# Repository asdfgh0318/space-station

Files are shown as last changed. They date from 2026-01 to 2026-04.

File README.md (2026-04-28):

<p align="center">
  space-station banner
</p>

# space-station

Multi-band radio telescope and antenna tracker — Raspberry Pi 4B + Waveshare Stepper Motor HAT (B) + 2× NEMA 17 + RTL-SDR. Fully 3D-printed alt-az mount, FastAPI dashboard, swappable RF feeds.

## Documentation

- **[`tech_stack.md`](tech_stack.md)** — north star: hardware stack and credentials
- **[`plan_2.md`](plan_2.md)** — active rebuild plan (current)
- **[`docs/archive/plan_1.md`](docs/archive/plan_1.md)** — historical Phase 1 plan
- **[`docs/archive/merge_plan.html`](docs/archive/merge_plan.html)** — upcoming `inmarsat-sniffer` integration plan

## Quick start

```bash
# On the Raspberry Pi (Debian Trixie)
bash scripts/bootstrap_rpi.sh
source ~/.bashrc
ss-test           # smoke-test motors (dry-run)
ss-start          # FastAPI dashboard on :8080
```

## Layout

```
tracker/      motor controller, geostationary look-angle math, sniffer stub
web/          FastAPI dashboard with Tracker + Inmarsat tabs
scripts/      bootstrap + bench test CLI
vendor/       reserved for inmarsat-sniffer submodule (not yet vendored)
docs/archive/ historical plans and integration design
```

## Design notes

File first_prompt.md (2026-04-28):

hi claude lets start building the radiotelescope i prepared a techstack.md file wich is our north star and wil be updated now lets tackle the first point of the file i want to connect on my bench the motors to the rpi hat and rpi i have an sdcard inserted lets setup github repo wich is ppublic and lets work this way you generate the plan of a stem and when im happy with your steps i accept it and then you make github isues out of all tasks and then execute them using a worktree of faster subagents after the plan is executed ill test the features and only then we commit

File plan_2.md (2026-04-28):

# plan_2 — Rebuild from scratch with inmarsat seams

## Context

The user is re-running the workflow from `first_prompt.md`: generate a plan → user
approves → GitHub issues → subagents in worktrees → user tests → commit. The previous
plan (`plan_1.md`) was executed at commit `bd0c259` and produced the current
`tracker/` + `web/` + `scripts/` + `requirements.txt`.

The user now wants a clean rebuild that bakes in **architectural seams for the
upcoming `inmarsat-sniffer` integration** (analyzed in `merge_plan.html`), without
actually pulling in the GPL-3.0 C binary yet. After this rebuild lands, the inmarsat
merge becomes a small, additive PR rather than a refactor.

Canonical sources of truth:
- `tech_stack.md` — Waveshare Stepper Motor HAT (B), NEMA 17, RTL-SDR, GUI control
- `tracker/config.yaml` (current) — 1:1 GT2 belt, 32× microstepping, Warsaw site
- `merge_plan.html` — target architecture for inmarsat sidecar

(Project memory is stale on the drive choice — it still says TMC2209 + 5:1. Will
update memory after the rebuild lands.)

---

## Scope

**Wipe:**
- `tracker/` (controller.py, config.yaml, __init__.py)
- `web/` (app.py, __init__.py)
- `scripts/` (bootstrap_rpi.sh, motor_test.py, spin_test.py)
- `requirements.txt`

**Move to `docs/archive/`:**
- `plan_1.md`
- `merge_plan.html`

**Keep untouched:**
- All `.stl`, `.STEP`, `.gcode`, `.pb`, `.pdf`, `.svg`, `.exe`
- `tech_stack.md`, `first_prompt.md`, `aplikacja_wok_rezydencja.md`, `README.md`
- `radio-telescope-plan.html`, `radio-telescope-plan.pdf`, `radio-telescope-plan-images/`
- `banner.svg`, `.gitignore`, `.git/`

**No code from `alphafox02/inmarsat-sniffer` enters this repo in this plan.**

---

## Target tree after rebuild

```
space-station/
├── tracker/
│   ├── __init__.py
│   ├── config.yaml          # HAT + bands + targets + sniffer seams
│   ├── controller.py        # lgpio motor control, ~300 LOC
│   ├── targets.py           # geostationary AZ/EL math, presets — STUB
│   └── sniffer.py           # subprocess supervisor placeholder — STUB
├── web/
│   ├── __init__.py
│   └── app.py               # FastAPI, jog UI, scaffolded "Inmarsat" tab — placeholder
├── scripts/
│   ├── bootstrap_rpi.sh     # OS bring-up + inmarsat build deps (no clone yet)
│   └── motor_test.py        # CLI bench tester
├── vendor/
│   └── .gitkeep             # reserved slot for inmarsat-sniffer submodule (later)
├── docs/
│   └── archive/
│       ├── plan_1.md
│       └── merge_plan.html
├── plan_2.md                # copy of this plan, committed at root
├── requirements.txt
├── tech_stack.md            (kept)
├── first_prompt.md          (kept)
├── README.md                (kept)
└── [all hardware assets kept]
```

---

## Tasks (one GitHub issue per task)

### Task 0 — Clean repo, archive old plans
- `git rm -r tracker/ web/ scripts/ requirements.txt`
- `mkdir -p docs/archive vendor`
- `git mv plan_1.md docs/archive/plan_1.md`
- `git mv merge_plan.html docs/archive/merge_plan.html`
- `touch vendor/.gitkeep`
- Verify with `git status` that only the targeted files moved/deleted
- **No commit yet** — gate on user testing per `first_prompt.md`

### Task 1 — `tracker/config.yaml` (with inmarsat seams)
Layout based on the current config but reorganized so future band/target/sniffer
config lives in well-named blocks instead of dormant `lnb:` and `sdr:` stubs:

```yaml
site:        # Warsaw 52.2297, 21.0122, 100m elevation
tracker:     # alt-az, driver: waveshare_hat_b, az/el axes (HAT pins, 1:1 belt, 32× µstep)
bands:                          # NEW — band profiles
  l_band:                       # 1525–1559 MHz Inmarsat
    enabled: false
    sample_rate: 2400000
    gain: 40.0
    notes: "Direct RTL-SDR, no LO/LNB"
  ku_band:                      # 10–12 GHz dish + LNB (future)
    enabled: false
    lnb:
      model: "Inverto IDLB-SINL40"
      lo_low: 9750000000
      lo_high: 10600000000
      switch_freq: 11700000000
      gpio:
        power_pin: 23
        voltage_select_pin: 25
        tone_pin: 26
targets:                        # NEW — geostationary presets, computed AZ/EL
  alphasat_25e:
    name: "Inmarsat 4F2 / Alphasat (25°E)"
    sat_longitude: 25.0
    band: "l_band"
  inmarsat_4f3_98w:
    name: "Inmarsat 4F3 (98°W)"
    sat_longitude: -98.0
    band: "l_band"
sniffer:                        # NEW — sidecar config, dormant until merge
  enabled: false
  binary_path: "vendor/inmarsat-sniffer/build/inmarsat-sniffer"
  feed_udp_port: 5000
  skip_c_channel: true          # Pi 4 default per upstream README
  web_port: 8888                # sniffer's own UI (iframed in our dashboard)
```

### Task 2 — `tracker/controller.py`
Same shape and quality as the current implementation (lgpio backend, trapezoidal
accel, click CLI, sim mode), built fresh:
- `StepperAxis` — step/dir/enable via lgpio
- `AntennaTracker` — two-axis orchestration, position state, jog/goto/home/park
- CLI: `status`, `goto az el`, `home`, `park`, `step --motor az/el --count N --dir cw/ccw`
- Sim fallback when lgpio unavailable
- ~300–400 LOC

### Task 3 — `tracker/targets.py` (STUB module)
Pure math, no I/O, no SDR, no submodule yet:
- `geostationary_azel(site_lat, site_lon, sat_lon) -> (az_deg, el_deg)`
  Standard formula: spherical geometry from observer to GEO arc.
- `load_targets(config) -> dict[name, Target]`
- `Target.dataclass(name, sat_longitude, band, az, el)`
- CLI smoke test: `python -m tracker.targets list` prints AZ/EL for each preset
  from current site coords (Warsaw → Alphasat ≈ 165°/27°).
- ~80 LOC. No subprocess, no SDR.

### Task 4 — `tracker/sniffer.py` (STUB module)
Placeholder for the future subprocess supervisor:
- `class SnifferSidecar` with `start()`, `stop()`, `status()`, `is_running()`
  All methods raise `NotImplementedError("inmarsat-sniffer not vendored yet — see docs/archive/merge_plan.html")` for now,
  so any caller sees a clear error.
- `SnifferStatus` dataclass (`pid`, `running`, `last_decode_at`, `decode_count`)
  defined now so the API is stable.
- ~40 LOC. Importable, doesn't crash, doesn't pretend to work.

### Task 5 — `scripts/motor_test.py`
Same scope as current implementation:
- `spin --motor 1/2 --steps N --speed S --dir cw/ccw`
- `sweep --motor N` — speed ramp
- `test-all` — both motors smoke test
- `interactive` — terminal arrow keys
- `--dry-run` flag, click + rich, reads `tracker/config.yaml`

### Task 6 — `scripts/bootstrap_rpi.sh`
Same structure as current Trixie bootstrap, plus inmarsat build deps preinstalled
so the future merge is a one-command `cmake && make`:

```bash
# Existing (motor + Python venv)
sudo apt install -y python3-lgpio python3-pip python3-venv pigpio-tools \
                    librtlsdr-dev rtl-sdr i2c-tools
# NEW — for future inmarsat-sniffer build
sudo apt install -y cmake build-essential pkg-config \
                    libacars2-dev libzmq3-dev libmosquitto-dev
```
- RTL-SDR udev rules + DVB blacklist (kept)
- I2C / USB-boot enablement (kept)
- Aliases: `ss-update`, `ss-start`, `ss-test`, `ss-debug` (kept)
- Smoke tests: lgpio connect, Python deps import, RTL-SDR detection
- Adds a TODO comment near the inmarsat deps pointing at `merge_plan.html`

### Task 7 — `web/app.py`
Same dashboard scope as today, plus a scaffolded "Inmarsat" tab:
- All current motor-control endpoints (`/api/jog`, `/api/goto`, `/api/home`,
  `/api/park`, `/api/motors/{enable,disable}`, `/api/stop`, `/api/set-limit`)
- `/ws` live position WebSocket
- Retro-terminal styling
- **NEW**: tab switcher in UI between "Tracker" (current) and "Inmarsat"
- **NEW**: `/api/sniffer/status` returns `{enabled: false, reason: "stub — see merge_plan"}`
- **NEW**: Inmarsat tab shows a "not configured yet — pending hardware/integration"
  placeholder card linking to `docs/archive/merge_plan.html`
- ~500–600 LOC

### Task 8 — `requirements.txt`
Same minimal set as today — no new deps for the sniffer stubs:
```
lgpio
fastapi
uvicorn[standard]
websockets
pyyaml
click
rich
numpy
```

### Task 9 — Save plan + write README hook
- Copy this plan file to repo root as `plan_2.md`
- Add a one-line section in `README.md` linking to `plan_2.md` and the
  archived `merge_plan.html` (README is currently essentially empty)

---

## Execution method (per `first_prompt.md`)

1. ☐ User approves this plan (via `ExitPlanMode`)
2. ☐ Create one GitHub issue per task (Task 0–9) with `gh issue create`
3. ☐ Spawn parallel subagents in **isolated git worktrees** — Tasks 1–8 are
   independent enough for parallel execution; Task 0 must run first; Task 9 last
4. ☐ User runs verification on RPi + bench
5. ☐ Only after user confirms tests pass, merge worktrees and commit

**Do not commit anything until the user has tested on hardware.**

---

## Verification

Run on the dev machine first:
- `python -c "from tracker.controller import AntennaTracker; AntennaTracker.from_config('tracker/config.yaml')"` — imports clean in sim mode
- `python -m tracker.targets list` — prints AZ/EL for Alphasat 25°E from Warsaw
  (expected: AZ ≈ 165°, EL ≈ 27°). Acts as numerical regression on the math.
- `python -c "from tracker.sniffer import SnifferSidecar; SnifferSidecar().status()"` — raises `NotImplementedError` cleanly
- `python scripts/motor_test.py test-all --dry-run` — no errors, both motors enumerated
- `uvicorn web.app:app --port 8080` → open browser → "Tracker" and "Inmarsat" tabs
  both render; Inmarsat tab shows the placeholder card
- `bash -n scripts/bootstrap_rpi.sh` — script parses, no syntax errors

Run on RPi (user does this on the bench):
- `bash scripts/bootstrap_rpi.sh` — completes without errors, all deps installed
- `python scripts/motor_test.py test-all` — both motors spin
- `python -m web.app --port 8080` → browser → arrow keys move motors
- Endpoint wizard saves limits to `config.yaml`

After the user signs off:
- Commit Task 0–9 as a single atomic rebuild commit (or one commit per task —
  user's call at commit time)
- Update memory: drive choice is HAT + 1:1, not TMC2209 + 5:1
- Push to `origin/main`

---

## What this plan does NOT do (deferred)

These are explicitly out-of-scope for this rebuild and belong to the inmarsat merge PR:
- Cloning `alphafox02/inmarsat-sniffer` as a submodule
- Building the C binary
- Writing the actual subprocess supervision logic
- UDP/MQTT decode listener
- Live decode WebSocket channel
- Iframe of the sniffer's :8888 UI
- L-band feed hardware acquisition decision
- Project root LICENSE selection (still no LICENSE file — to be settled before
  pulling in GPL-3.0 code, **before** the merge PR, not in this rebuild)

The seams in this plan make those changes additive, not invasive.

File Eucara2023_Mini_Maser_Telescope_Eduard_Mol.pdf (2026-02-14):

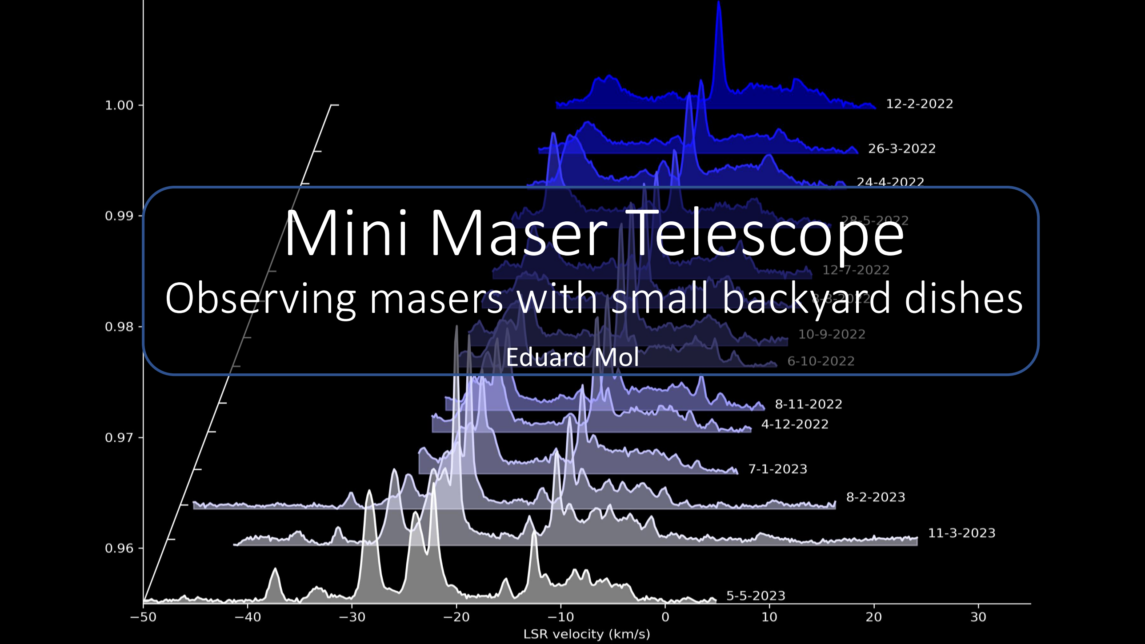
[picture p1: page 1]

# Mini Maser Telescope

## Observing masers with small backyard dishes

Eduard Mol

## What are masers? (and why are they interesting?)

- Essentially the microwave equivalent of LASERs
- Stimulated emission
- Specific molecules:
- OH (1612- 1720 MHz),
- methanol (6.668 and 12.2 GHz)
- water (22.2 GHz)
- Star formation and red giant stars
- Variable

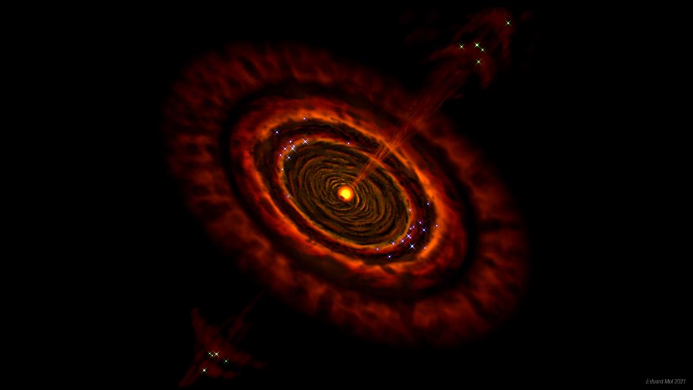
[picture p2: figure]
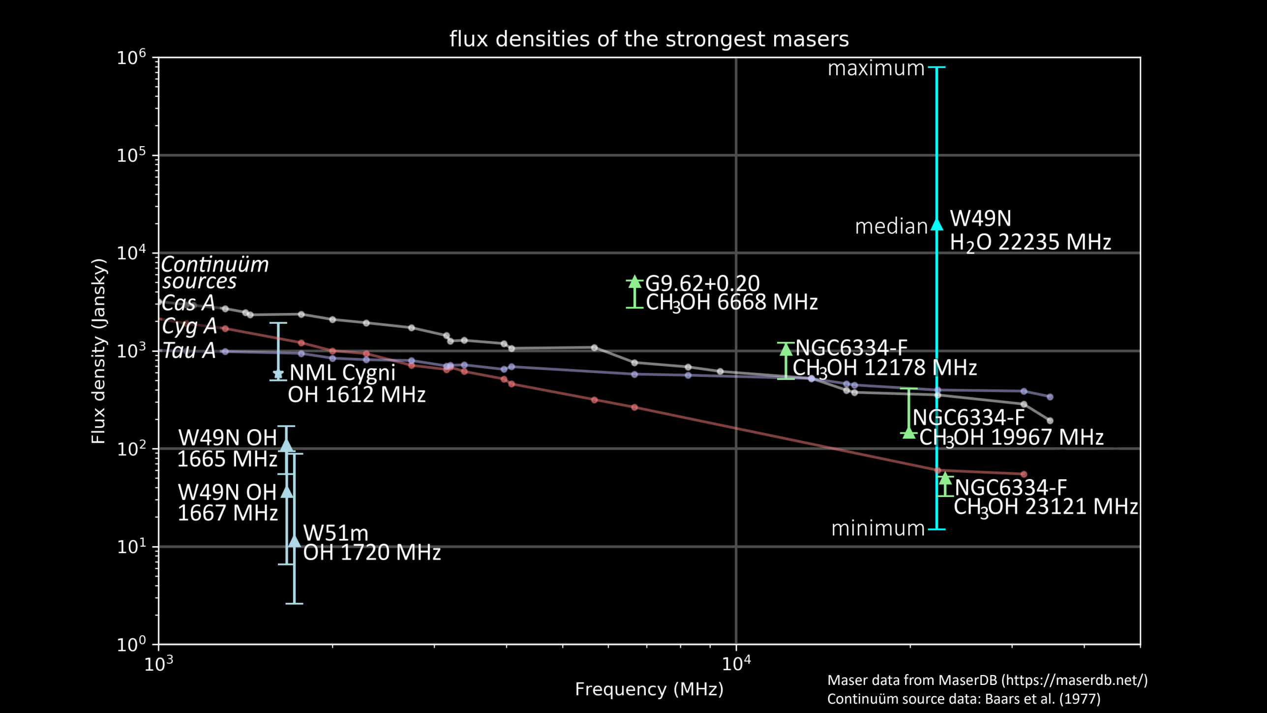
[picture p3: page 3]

Maser data from MaserDB (https://maserdb.net/) Continuüm source data: Baars et al. (1977)

## 12.2 GHz methanol masershardware and observation methods

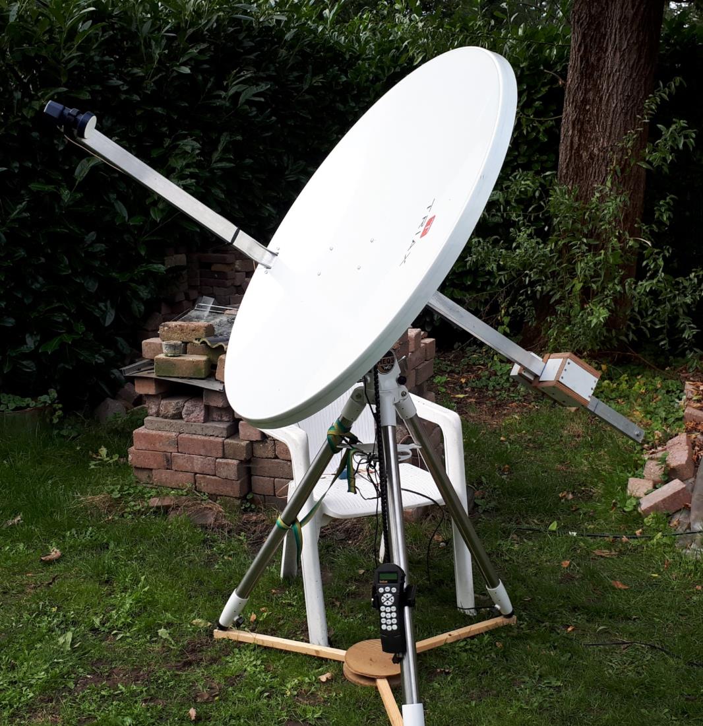
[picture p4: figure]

- 1 metre dish on HEQ5 mount
- Inverto Ku band PLL LNB
- 22KHz tone for band switching
- Software: SDR#/ IF average
- Post-processing in python/ excel
- Frequency to LSR velocity

## 12.2 GHz methanol masers: results

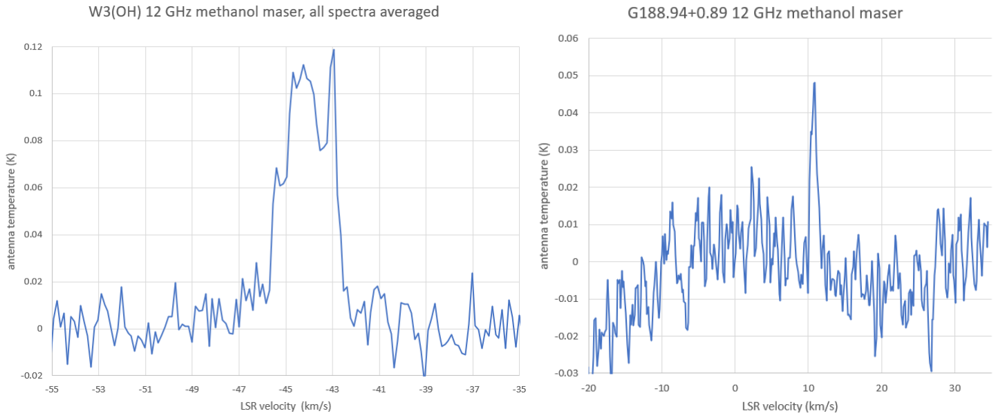
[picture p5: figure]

- W3(OH)
- G188.94+0.89

## Water masers at 22.2 GHz

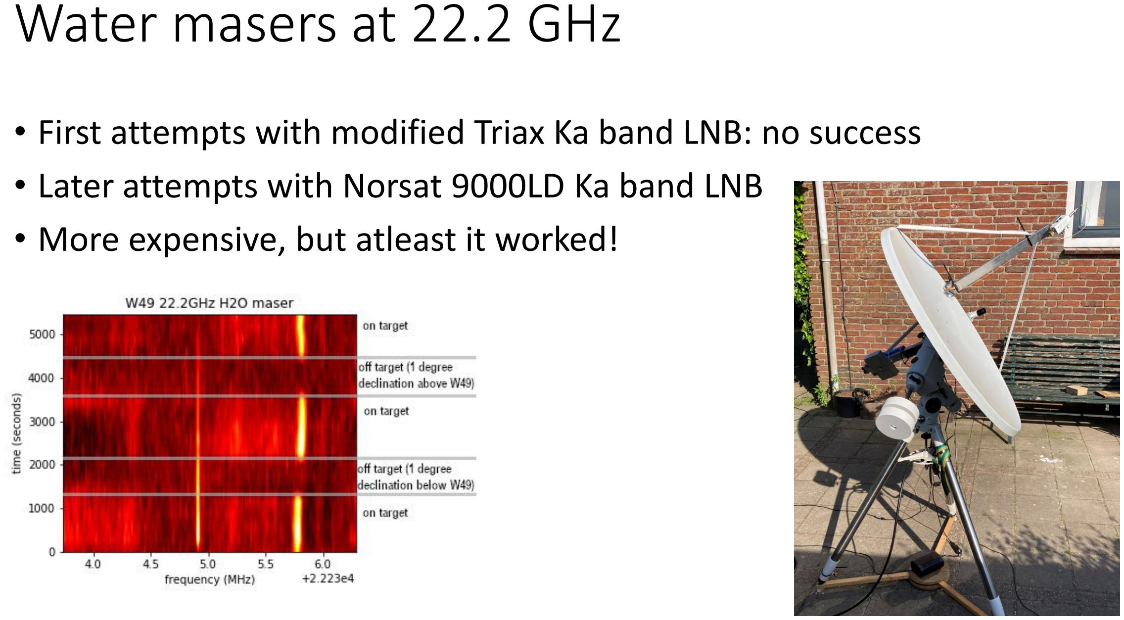
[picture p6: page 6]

- First attempts with modified Triax Ka band LNB: no success
- Later attempts with Norsat 9000LD Ka band LNB
- More expensive, but atleast it worked!

## 22.2 GHz setup technical info

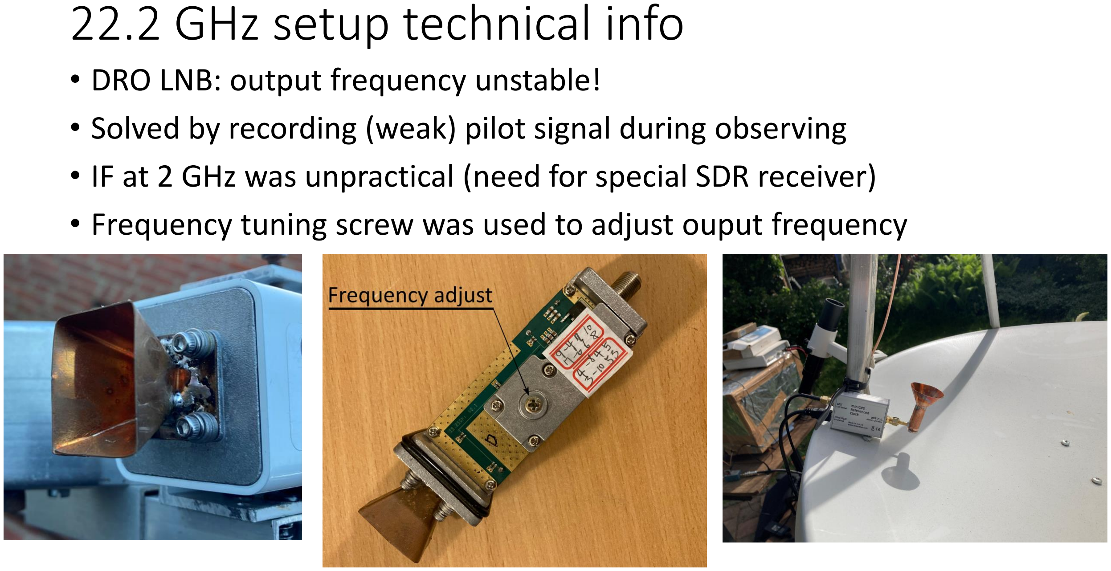
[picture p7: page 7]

- DRO LNB: output frequency unstable!
- Solved by recording (weak) pilot signal during observing
- IF at 2 GHz was unpractical (need for special SDR receiver)
- Frequency tuning screw was used to adjust ouput frequency

## Water masers: The results so far

- Several sources were detected:
1. W49
2. W51
3. W3(OH)/ W3(2)
4. Orion KL
5. W75
6. G34.403+0.232
7. Cepheus A
8. NML Cygni
9. G25.624+1.050

W49

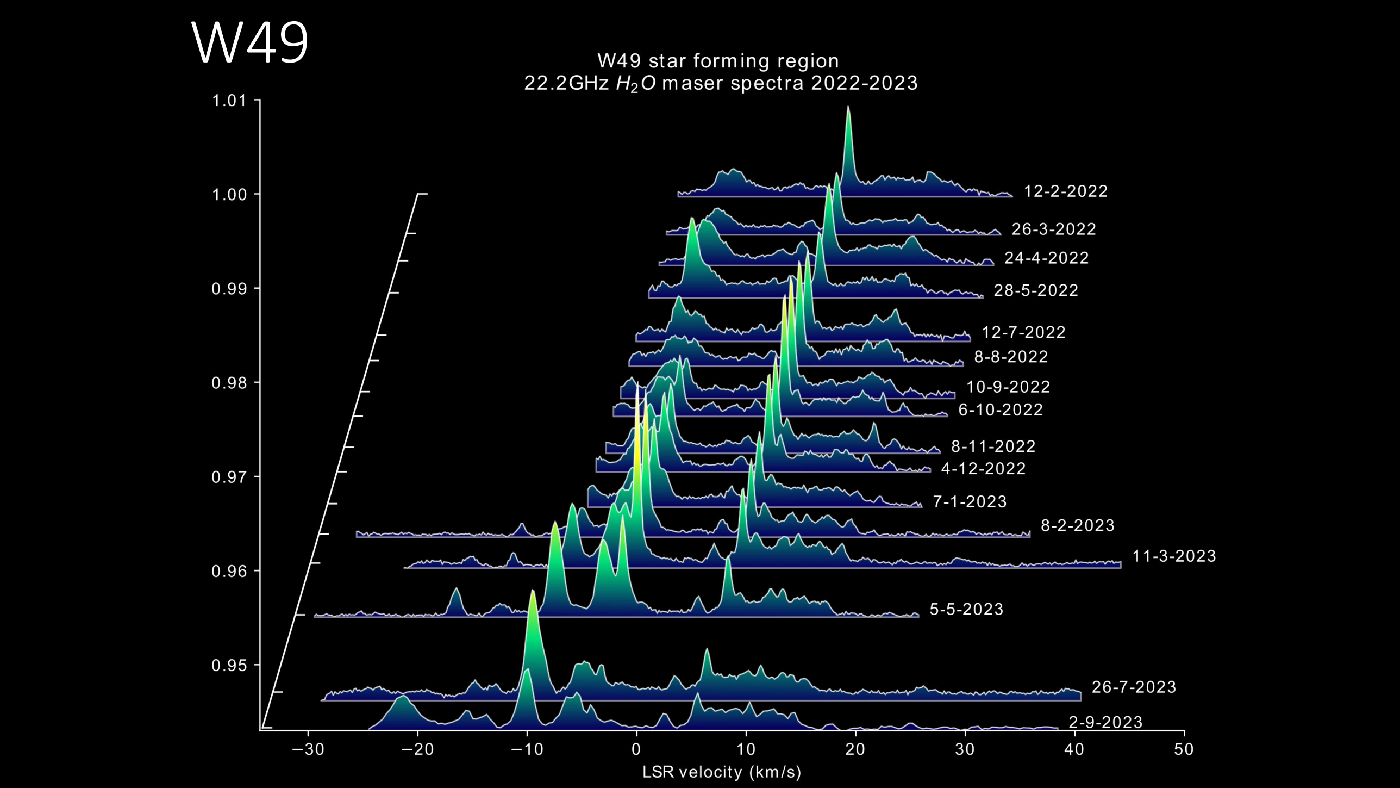
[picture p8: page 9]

## Conclusion and outlook

- 12.2 GHz Methanol masers:
+ Relatively easy and cheap to set up
- 12.2 GHz masers are challenging to detect
- 22.2 GHz Water masers
+ several sources can be detected
+ Tracking variability is possible
- equipment is more expensive/ more difficult to obtain

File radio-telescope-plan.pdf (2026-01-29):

Prepared January 2026 | For review and consultation

# Radio Telescope & Antenna Tracker Project

## Project Vision

Incremental build of an antenna-tracked radio telescope system, starting with automated weather satellite reception and a weather prediction AI for Warsaw, then expanding into radio astronomy and citizen science contributions.

## PHASE 1: Automated Weather Satellite Station +

## Weather AI

### 1A: Meteor-M LRPT Reception (No Tracker Needed) — ~$60-100

The easiest and fastest entry point. Meteor-M N2-3/N2-4 are Russian polar-orbiting weather satellites transmitting at 137 MHz. Multiple passes over Warsaw daily. No tracking needed (omnidirectional antenna). Will be available into the 2040s.

Important context: All NOAA POES satellites (15, 18, 19) were decommissioned in mid-2025. Meteor-M is now the primary 137 MHz weather satellite. From Warsaw, GOES satellites are NOT visible (geostationary over Americas).

Hardware

Item | Cost | Notes
RTL-SDR Blog V4 | ~$35 | Main receiver
QFH antenna (DIY) | ~$10-15 | Copper pipe + PVC, circularly polarized
SAW filter + LNA (137 MHz) | ~$15-25 | Optional but recommended for Warsaw RFI
Raspberry Pi 4/5 | ~$50-80 | Or use existing PC
SMA cables, adapters | ~$10

Software Stack

SatDump (satdump.org) — all-in-one: satellite tracking, SDR control, decoding, image generation. Has built-in automation (auto-track, auto-record, auto-decode). Replaces the old chain of 6+ programs

Runs on Raspberry Pi 5 or any Linux box

Outputs: visible light images, infrared images, false-color composites, map overlays

What you get

1 km/px resolution images of Europe (JPEG compressed but good)

3 spectral channels (visible, near-IR, thermal IR)

Multiple passes/day, automated capture 24/7

Cloud patterns, storm systems, snow cover over Warsaw region

### 1B: HRPT Reception with Antenna Tracker — ~$300-500 additional

The big upgrade: high-resolution, uncompressed multi-channel imagery. This requires building the antenna tracker (your main engineering project).

•

•

•

•

•

•

•

Receivable satellites from Warsaw with HRPT (1.7 GHz, L-band)

Satellite | Operator | Status | Data
Meteor-M N2-3 | Roscosmos | Active | 6 channels, 1 km, uncompressed
Meteor-M N2-4 | Roscosmos | Active | 6 channels, 1 km, uncompressed
Metop-B | EUMETSAT | Until ~2027 | 6 channels AVHRR, 1 km
Metop-C | EUMETSAT | Until ~2030 | 6 channels AVHRR, 1 km
AWS (Arctic Weather Sat) | ESA | Active | Microwave radiometer

Hardware — Antenna Tracker (custom build)

Item | Cost | Notes
2x NEMA23 stepper motors | $30-60 | Torque for dish + wind
2x TMC2209 stepper drivers | $10-20 | Silent, reliable
ESP32 dev board | $8-12 | Rotator controller
GT2 timing belt + pulleys (80T+20T) | $15-20 | 4:1 first stage reduction
Worm gear set (or 3D printed) | $15-30 | Second stage, 10:1-15:1
6200/6201 bearings (4-6x) | $10-20 | AZ and EL axes
2040 aluminum extrusion | $20-40 | Frame structure
3D printed parts (PETG) | $20-25 | Gear housings, mounts, adapters
Slip ring (12-wire) | $10-15 | Cable management through AZ axis
Steel plate/tube (base) | workshop | Welded base for rooftop mount
Weatherproof enclosure | $15-25 | For electronics
AS5600 magnetic encoders (2x) | $5-10 | Position feedback

Hardware — RF Chain

Item | Cost | Notes
80-100cm offset satellite dish | $0-50 | Used, from classifieds (OLX.pl)
L-band helicone feed (3D printed) | $5-10 | Popular open-source design
Nooelec SAWbird+ GOES LNA | ~$35 | 0.5 dB NF, filtered for 1.7 GHz
Airspy Mini (upgrade from RTL-SDR) | ~$100 | 12-bit, 6 MHz BW, much better for HRPT

Tracker Software (your code)

Rotator Controller (ESP32, C/C++):
├── Stepper motor control (AccelStepper library) ├── AS5600 encoder feedback (I2C)
├── EasyComm2 protocol over serial/WiFi
├── Web interface for manual control
├── Homing routine (limit switches or encoder) └── Wind stow mode (auto-park in high wind)

Host Software (Python, Raspberry Pi):
├── SatDump integration (autotrack + decode)
├── Satellite pass prediction (pyorbital/skyfield) ├── Rotator command interface (rotctld/Hamlib) ├── Image post-processing pipeline
├── Database for captured images + metadata
└── API for weather AI module

What you get

1 km/px UNCOMPRESSED images, 6 spectral channels

Thermal IR for cloud-top temperatures

Near-IR for vegetation, water vapor

Multiple satellites per day = more frequent coverage of Warsaw

Raw data for serious weather analysis

### 1C: Geostationary Satellite Reception (Fixed Dish) — ~$50-150

### additional

Add continuous weather monitoring from Elektro-L (Russian geostationary satellite being repositioned to cover Europe in late 2025/2026).

•

•

•

•

•

Setup

Small fixed dish (60-80cm) pointed at Elektro-L N°3 (14.5°W from Warsaw = ~30° elevation, ~245° azimuth)

Same L-band LNA + SDR as HRPT setup (can share or add second RTL-SDR)

SatDump decodes LRIT/HRIT

Full-disk images every 30 minutes, continuously

Alternative: EUMETCast via DVB-S2 — standard satellite TV setup pointed at Hotbird 13°E, provides Meteosat data. Requires EUMETSAT registration (free for non-commercial/educational use).

### 1D: Weather Prediction AI — Software Project

This is the software centerpiece: an AI system that learns weather patterns from your satellite imagery and predicts weather for Warsaw.

•

•

•

•

Architecture

┌─────────────────────────────────────────────────────────┐
│ | Weather AI System | │
├─────────────────────────────────────────────────────────┤
│ | | │
│ DATA COLLECTION | │
│ ├── Satellite images (your captures) | │
│ │ | ├── Meteor-M LRPT (137 MHz, automated) | │
│ │ | ├── Meteor-M/Metop HRPT (1.7 GHz, tracked) | │
│ │ | └── Elektro-L HRIT (geostationary, continuous) | │
│ ├── Ground truth weather data | │
│ │ | ├── IMGW API (Polish Met Institute) | │
│ │ | ├── OpenWeatherMap API (current + historical) | │
│ │ | └── Your own weather station (optional, future) | │
│ └── Timestamp + geolocation metadata | │
│ | | │
│ DATA PIPELINE | │
│ ├── Image preprocessing | │
│ │ | ├── Georeferencing (map projection) | │
│ │ | ├── Crop to Warsaw region (~200km radius) | │
│ │ | ├── Normalize channels | │
│ │ | ├── Cloud classification (IR thresholding) | │
│ │ | └── RFI artifact removal | │
│ ├── Feature extraction | │
│ │ | ├── Cloud coverage % | │
│ │ | ├── Cloud motion vectors (consecutive images) | │
│ │ | ├── Cloud-top temperature distribution | │
│ │ | ├── Visible albedo patterns | │
│ │ | └── Temporal sequences (last N images) | │
│ └── Storage (PostgreSQL + image files) | │
│ | | │
│ AI MODELS | │
│ ├── Nowcasting (0-6 hours) | │
│ │ | ├── ConvLSTM / U-Net for cloud motion prediction | │
│ │ | ├── Input: sequence of satellite images | │
│ │ | └── Output: predicted cloud/rain patterns | │
│ ├── Short-term forecast (6-24 hours) | │
│ │ | ├── Transformer-based sequence model | │
│ │ | ├── Input: satellite images + weather features | │
│ │ | └── Output: temperature, precipitation, cloud cover │
│ └── Evaluation | │
│ | ├── Compare vs actual weather (IMGW data) | │
│ | ├── Compare vs official forecast (IMGW/ECMWF) | │
│ | ├── Track accuracy metrics over time | │
│ | └── Skill score relative to persistence forecast | │
│ | | │
│ DASHBOARD (Web) | │
│ ├── Live satellite image viewer | │
│ ├── AI prediction display with confidence | │
│ ├── Comparison: AI vs actual vs official forecast | │
│ ├── Historical accuracy charts | │
│ └── Alerts for severe weather detection | │
│ | | │
└─────────────────────────────────────────────────────────┘

Tech Stack

Python — main language (PyTorch/TensorFlow, SatDump integration, data pipeline)

PostgreSQL + TimescaleDB — time-series weather data + image metadata

FastAPI — backend API

React or Svelte — dashboard frontend

PyTorch — model training (ConvLSTM, U-Net, or transformer)

Docker — containerized deployment on Raspberry Pi 5 or mini PC

Open-Source Models to Build On

NPM (github.com/seominseok0429/Data-driven-Precipitation-Nowcasting-Using-Satellite-Imagery) — directly uses satellite imagery, 2 km resolution

OpenClimatefix skillful_nowcasting — DeepMind DGMR reimplementation

ConvLSTM implementations for sequence prediction

Awesome-LWMs (github.com/jaychempan/Awesome-LWMs) — curated list of weather AI models

Training Data Strategy

Bootstrap: Start collecting satellite images + corresponding IMGW weather data from day 1

Pre-train: Use publicly available satellite datasets (SEVIR, EarthNet2021) for initial model training

Fine-tune: Once you have weeks/months of Warsaw-specific data, fine-tune on your own captures

Iterate: Continuously retrain as more data accumulates

Warsaw-Specific Weather Data Sources

IMGW (Instytut Meteorologii i Gospodarki Wodnej) — Polish meteorological data API

OpenWeatherMap — free tier: current weather, 5-day forecast, historical data

Open-Meteo — free, open-source weather API, historical + forecast data

ECMWF — European Centre for Medium-Range Weather Forecasts (open data)

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
## PHASE 2: Radio Astronomy (Future, ~$100-300

## additional)

After the weather station is operational, add radio astronomy capability to the same tracked dish:

Swap/add a 1420 MHz feed horn + SAWbird+ H1 LNA

Hydrogen line detection and Milky Way mapping

Join SARA, contribute data

Same tracker, same SDR infrastructure

PHASE 3: Large Dish + Advanced Targets (Future, ~$500-1500)

Upgrade to 2-3m dish (used TVRO)

Upgrade SDR to SDRplay RSPdx (14-bit)

Pulsar detection attempts

Join SatNOGS network, Wow@Home

Multi-band capability

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
## Project Repository Structure

space-station/
├── firmware/ | # ESP32 rotator controller
│ | ├── src/
│ | │ | ├── main.cpp
│ | │ | ├── stepper_control.cpp
│ | │ | ├── easycomm.cpp | # EasyComm2 protocol
│ | │ | ├── encoder.cpp | # AS5600 position feedback
│ | │ | └── web_server.cpp | # Status + manual control
│ | └── platformio.ini
├── tracker/ | # Host-side tracking software
│ | ├── scheduler.py | # Satellite pass scheduler
│ | ├── rotator.py | # Rotator communication
│ | ├── satdump_integration.py # SatDump automation hooks
│ | └── config.yaml
├── weather-ai/ | # Weather prediction AI
│ | ├── data/
│ | │ | ├── collectors/ | # IMGW, OpenWeatherMap scrapers
│ | │ | ├── pipeline.py | # Image preprocessing
│ | │ | └── dataset.py | # PyTorch dataset class
│ | ├── models/
│ | │ | ├── nowcast.py | # ConvLSTM nowcasting model
│ | │ | ├── forecast.py | # Transformer forecast model
│ | │ | └── evaluate.py | # Accuracy metrics
│ | ├── api/
│ | │ | └── main.py | # FastAPI backend
│ | └── train.py
├── dashboard/ | # Web frontend
│ | ├── src/
│ | └── package.json
├── hardware/ | # CAD files, wiring diagrams
│ | ├── rotator/ | # 3D print STL files
│ | ├── antenna/ | # QFH, feed horn designs
│ | └── enclosure/
├── docs/
│ | ├── build-guide.md
│ | └── calibration.md
├── docker-compose.yml
└── README.md

## Implementation Order

### Sprint 1: Get Images Flowing

Order RTL-SDR V4, build QFH antenna

Install SatDump on Raspberry Pi / PC

Receive first Meteor-M LRPT image

Set up automated capture (SatDump autotrack)

Build image storage database

Start collecting IMGW/Open-Meteo weather data for Warsaw

### Sprint 2: Build the Tracker

Design rotator in CAD (Fusion 360 / FreeCAD)

3D print gear housings and structural parts

Weld steel base frame

Assemble mechanical system

Write ESP32 firmware (stepper control + EasyComm2)

Integrate with SatDump for automated HRPT tracking

### Sprint 3: HRPT Reception

Acquire/build dish (80-100cm) + L-band feed

Install LNA + cabling

First tracked HRPT capture

Set up multi-satellite automated schedule

### Sprint 4: Weather AI v1

Build data pipeline (satellite images → preprocessed dataset)

Implement baseline model (ConvLSTM for cloud motion)

Train on accumulated data + public datasets

Build dashboard with live images + predictions

Start tracking prediction accuracy vs actual weather

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
### Sprint 5: Iterate & Expand

Improve AI model based on accuracy data

Add Elektro-L geostationary reception

Add radio astronomy capability (1420 MHz feed)

Join SARA / SatNOGS communities

## Verification

### Phase 1A (LRPT)

First Meteor-M image captured within first evening

SatDump autotrack captures 4+ passes per day unattended

Images show recognizable cloud patterns over Europe

### Phase 1B (HRPT + Tracker)

Rotator responds correctly to EasyComm2 commands

Gpredict satellite tracking test: rotator follows predicted pass

HRPT image quality visibly superior to LRPT (sharper, more channels)

Tracker survives wind test (weights attached to simulate dish wind load)

### Phase 1D (Weather AI)

Dashboard shows latest satellite images + weather data

Nowcast model produces cloud predictions for next 1-3 hours

Track "skill score" vs persistence baseline (just predicting "same as now")

After 1+ month of data: compare AI accuracy vs IMGW official forecast

## Sources

SatDump (https://www.satdump.org/) — all-in-one satellite decoding software

Beyond POES: Amateur Satellite Reception (https://www.satdump.org/posts/beyond-poes-amateur-satellite-reception/) — post-NOAA landscape

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
Meteor-M Reception Guide (https://www.a-centauri.com/articoli/meteor-satellite-reception) — Jacopo's comprehensive guide

HRPT Beginners Guide (https://www.rtl-sdr.com/a-comprehensive-beginners-guide-to-hrpt-weather-satellite-reception/)

SatDump Automation (https://www.rtl-sdr.com/automating-noaa-apt-and-meteor-m2-lrpt-reception-with-satdump-1-1-2/)

Tysonpower DIY Rotator (https://www.rtl-sdr.com/building-a-diy-azel-antenna-rotator-for-satellite-tracking/)

SatNOGS Rotator v3 (https://wiki.satnogs.org/SatNOGS_Rotator_v3)

NPM Precipitation Nowcasting (https://github.com/seominseok0429/Data-driven-Precipitation-Nowcasting-Using-Satellite-Imagery)

DGMR Reimplementation (https://github.com/openclimatefix/skillful_nowcasting)

Awesome Large Weather Models (https://github.com/jaychempan/Awesome-LWMs)

SARA (https://radio-astronomy.org/) — Society of Amateur Radio Astronomers

SatNOGS (https://satnogs.org/) — satellite ground station network

Radio JOVE (https://science.nasa.gov/citizen-science/radio-jove/)

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
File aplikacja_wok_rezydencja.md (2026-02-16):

# Aplikacja na rezydencję WOK Warszawa 2026
## Temat przewodni: EKSPERYMENT

**Zespół:** Adam, Stas, Maksym (@dontriskit)
**Projekt:** Radioteleskop DIY + system neonów reaktywnych na dane SDR

---

## Tekst kuratorski (kontekst)

> Tegorocznym hasłem przewodnim jest eksperyment. To właśnie przestrzeń spokojnej pracy, nieśpiesznej eksploracji własnych pomysłów, taka, która sprzyja podążaniu za ciekawością, wydaje nam się dziś szczególnym luksusem. Eksperymentowanie wymaga namysłu, w niektórych wypadkach implikuje doświadczenia zmysłowe, w innych – ich brak. W każdym wypadku z eksperymentem wiąże się ryzyko nierozpoznania, bycia niezrozumianym, zdezinterpretowaną. Podczas eksperymentowania w WOK osoby twórcze będą mogły w możliwie bezpiecznej przestrzeni prototypować, testować pomysły i rozwiązania oraz swobodnie podążać za własnym procesem. To, co zostaje po eksperymentowaniu z eksperymentem, nie jest produktem, nie podlega logice utowarowienia, lecz pozostaje świadectwem trajektorii…

---

## 1. Jak rozumiecie temat tegorocznej edycji rezydencji?
*(maksymalnie 1800 znaków ze spacjami)*

Eksperyment to słowo, które jednakowo silnie rezonuje w laboratorium i w pracowni. W nauce to kontrolowana procedura – hipoteza, pomiar, weryfikacja. W sztuce to gest otwarcia na niewiadome. Nasz projekt lokuje się dokładnie na tym przecięciu i czerpie z obu tradycji, nie przynależąc w pełni do żadnej.

Budujemy radioteleskop – urządzenie do odbioru fal elektromagnetycznych z kosmosu. To dosłowny eksperyment: nie wiemy, co usłyszymy. Fale radiowe są niewidoczne, niesłyszalne, niewyczuwalne bez pośrednictwa technologii. Eksperymentujemy więc z samym aktem percepcji – rozszerzamy ludzkie zmysły za pomocą anteny, odbiornika SDR i kodu, próbując uchwycić to, co jest obecne wokół nas, ale niedostępne. Tekst kuratorski mówi o doświadczeniach zmysłowych i ich braku – nasz projekt żyje właśnie w tej szczelinie: czynimy słyszalnym to, co z natury jest nieme.

Eksperymentujemy też z materialnością i ekonomią narzędzi. Teleskop jest drukowany 3D z recyklingowanych części, za budżet poniżej 200 euro. Testujemy, czy narzędzia obserwacji kosmosu mogą istnieć poza instytucjami dysponującymi dużymi środkami – demokratyzacja nasłuchu jako praktyka twórcza. Pracujemy w trójkę, łącząc programowanie, elektronikę i rzeźbę świetlną – sam ten układ jest eksperymentem w kolaboracji.

System neonów, przekształcający dane radiowe w pulsacje światła, jest eksperymentem translacji – próbą nadania widzialnej, cielesnej formy temu, co niezmysłowe. Ryzykujemy niezrozumienie: czy to nauka? Czy sztuka? Ale właśnie ta nieokreśloność, ta przestrzeń między dyscyplinami, jest naszym miejscem pracy. Eksperyment rozumiemy jako prawo do procesu bez gwarancji produktu – do podążania za sygnałem, dosłownie i metaforycznie, bez pewności, dokąd nas zaprowadzi.

---

## 2. Koncepcja na proces rezydencyjny
*(maksymalnie 1800 znaków ze spacjami)*

Nasz proces rezydencyjny składa się z trzech splecionych ścieżek, które zbiegają się w instalację – otwartą stację nasłuchową. Pracujemy jako trio – każdy wnosi odmienną wrażliwość i kompetencję, a proces wzajemnego uczenia się jest częścią eksperymentu.

Pierwsza ścieżka: budowa. Drukujemy 3D elementy mechaniczne trackera antenowego, montujemy obrotowe mocowanie na osi azymutu i elewacji, kalibrujemy system automatycznego śledzenia obiektów na niebie. Pracujemy z otwartym kodem, drukarką Ender 3 i odbiornikiem RTL-SDR podłączonym do Raspberry Pi. To proces z natury powolny – każdy wydruk trwa godziny, kalibracja wymaga powtarzalnych, cierpliwych prób. Czas druku staje się czasem namysłu i rozmowy.

Druga ścieżka: translacja. Stas buduje system neonowych lamp reagujących na strumień danych z odbiornika SDR w czasie rzeczywistym. Sygnały satelitów meteorologicznych, emisja wodoru na częstotliwości 1420 MHz, kosmiczny szum tła – zostają przełożone na pulsacje, rytmy i natężenie światła. Nie w logice precyzyjnej wizualizacji danych, lecz bliżej synestezji – neon jako zmysł, którego nam brakuje, organ percepcji radiowej.

Trzecia ścieżka: nasłuch. Regularne sesje obserwacyjne, podczas których kierujemy antenę w różne obszary nieba i słuchamy. Sesje są otwarte – zapraszamy współrezydentów i odwiedzających. Nie obiecujemy odkrycia. Obiecujemy uważność wobec sygnałów, które docierają do nas nieustannie, niezależnie od tego, czy ktokolwiek ich słucha.

Po rezydencji pozostanie działająca stacja, archiwum sesji i otwarty kod – zapis trajektorii eksperymentu. Wszystko publikujemy open source, zapraszając innych do kontynuacji i modyfikacji. Eksperyment nie kończy się z rezydencją – rozgałęzia się, staje się wspólny, wymyka się autorom.

---

## Notatki robocze

### Kluczowe motywy do podkreślenia:
- **Nieśpieszność** – druk 3D = godziny czekania, kalibracja = powtarzalność, nasłuch = cierpliwość
- **Ryzyko niezrozumienia** – projekt na granicy sztuki i nauki, żadna strona nie "uznaje" w pełni
- **Nie-produkt** – stacja nasłuchowa to proces, nie obiekt; dane płyną, neony pulsują, nic nie jest "skończone"
- **Demokratyzacja** – <200 EUR, open source, drukarka za 800 zł
- **Zmysłowość / jej brak** – fale radiowe → neon = czynienie niewidzialnego widzialnym
- **Trajektoria** – archiwum sesji jako zapis drogi, nie celu

### Elementy techniczne projektu:
- Radioteleskop: RPi 4 + RTL-SDR, PETG 3D print, belt-driven alt-az mount
- Pasma: VHF (137 MHz weather sats), L-band (1420 MHz hydrogen), Ku-band (12.2 GHz masers)
- System neonów: dane SDR → przetwarzanie → sterowanie jasnością/pulsacją neonów
- Całość open source na GitHub

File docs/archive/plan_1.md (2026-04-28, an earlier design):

# Step 1: Bench Motor Control via Waveshare Stepper Motor HAT (B)

## Context

Starting fresh. The user has a Raspberry Pi 4B with a Waveshare Stepper Motor HAT (B) and 2x NEMA 17 steppers on the bench. Old Phase 0 code (written for TMC2209 standalone drivers) is being deleted — we start over with the Waveshare HAT approach.

- `tech_stack.md` is the north star
- Belt drive: 1:1, 20T GT2 pulleys on both ends
- Microstepping: DIP switches only (no software control)
- Resolution at 1/16: 200 × 16 × 1 = 3200 microsteps/rev → 0.1125°/step
- Credentials in `tech_stack.md` — leave as-is

---

## Tasks

### 0. Clean repo — delete old code & docs
**Delete these directories entirely:**
- `tracker/` — old TMC2209 controller code
- `sdr/` — SDR capture/processing
- `web/` — old FastAPI dashboard
- `weather/` — empty collectors
- `targets/` — maser catalog (will recreate if needed)
- `scripts/` — old install script
- `hardware/` — outdated CAD (worm gear), specs, wiring
- `docs/` — old project plan & research
- `data/` — empty data dirs

**Delete these files:**
- `requirements.txt` — will recreate for new stack

**Keep:**
- All `.stl`, `.gcode`, `.STEP` files
- `.pb` files (raw data)
- `tech_stack.md`, `first_prompt.md`
- `README.md`, `banner.svg`, `.gitignore`
- `aplikacja_wok_rezydencja.md`
- PDFs (`Eucara2023...`, `radio-telescope-plan.pdf`)
- `radio-telescope-plan-images/`
- `Windows11InstallationAssistant.exe`

### 1. Create `tracker/config.yaml` — HAT pin mapping + belt drive
- Waveshare HAT (B) GPIO pins (STEP/DIR/ENABLE only, no mode pins):
  - Motor 1 (AZ): STEP=19, DIR=13, ENABLE=12
  - Motor 2 (EL): STEP=18, DIR=24, ENABLE=4
- Belt drive 1:1, 20T GT2 pulleys, 200 steps/rev, 1/16 microstepping
- `home_switch_enabled: false` for bench mode
- Site: Warsaw coordinates
- Pin mapping to be verified against Waveshare wiki during implementation

### 2. Create `tracker/controller.py` — motor controller for Waveshare HAT (B)
Fresh, lean motor controller (~300 LOC) built for the HAT:
- `StepperAxis` class: step/dir/enable GPIO control via pigpio (RPi.GPIO fallback)
- `AntennaTracker` class: two-axis control, position tracking
- Trapezoidal acceleration profiles
- Bench mode: skip homing when no limit switches
- CLI: `--status`, `--goto az el`, `--home`, `--park`, `--steps motor count`

### 3. Create `scripts/motor_test.py` — bench test CLI
Standalone test tool (~200 LOC) using `click` + `rich`:
- `spin --motor 1 --steps 200 --speed 100 --dir cw`
- `sweep --motor 1` — speed ramp test
- `test-all` — smoke test both motors
- `interactive` — arrow keys control in terminal
- `--dry-run` for testing without GPIO
- Loads pins from `tracker/config.yaml`

### 4. Create `web/app.py` — GUI control panel
Fresh web dashboard (~400 LOC) with FastAPI:
- **Position display**: current az/el in degrees + step count
- **Keyboard control**: Arrow keys = jog, Shift+Arrow = fast jog, Space = stop
- **Jog pad**: visual arrow buttons + step size selector (0.01°–45°)
- **Motor enable/disable** toggle
- **Endpoint wizard**: capture current position as axis limit, save to config
- **Bench mode indicator**: shows when homing switches are disconnected
- WebSocket live position updates

### 5. Create `scripts/bootstrap_rpi.sh` — RPi setup script
Bootstrap script (~100 LOC) for fresh RPi OS:
- Install system packages (pigpio, i2c-tools, rtl-sdr, etc.)
- Enable I2C, start pigpiod
- Clone repo / git pull
- Python venv + requirements
- Convenience aliases: `ss-update`, `ss-start`, `ss-test`
- Smoke test (pigpio connection)

### 6. Create `requirements.txt` — fresh dependencies
Only what's needed for the HAT motor control + web UI:
- pigpio, RPi.GPIO (motor control)
- fastapi, uvicorn, websockets (web UI)
- pyyaml (config)
- click, rich (CLI tools)
- numpy (if needed for calculations)

---

## Files Summary

| File | Action | Scope |
|---|---|---|
| `tracker/`, `sdr/`, `web/`, etc. | Delete | Clean old code |
| `tracker/config.yaml` | New | HAT config |
| `tracker/controller.py` | New | ~300 LOC |
| `scripts/motor_test.py` | New | ~200 LOC |
| `web/app.py` | New | ~400 LOC |
| `scripts/bootstrap_rpi.sh` | New | ~100 LOC |
| `requirements.txt` | New | Fresh deps |

---

## Execution Method (from first_prompt.md)

1. **This plan** → user approves
2. **Create GitHub issues** — one per task (0–6)
3. **Execute in worktree** — launch subagents in isolated worktrees to implement each task
4. **User tests** on the bench (RPi + HAT + motors)
5. **Commit only after testing passes**

---

## Verification

1. **On dev machine**: `python scripts/motor_test.py test-all --dry-run` — no errors
2. **On RPi**: `bash scripts/bootstrap_rpi.sh` — all deps installed
3. **On RPi**: `python scripts/motor_test.py test-all` — both motors spin
4. **On RPi**: `python -m web.app --port 8080` → open browser → arrow keys move motors
5. **On RPi**: endpoint wizard saves limits to config.yaml

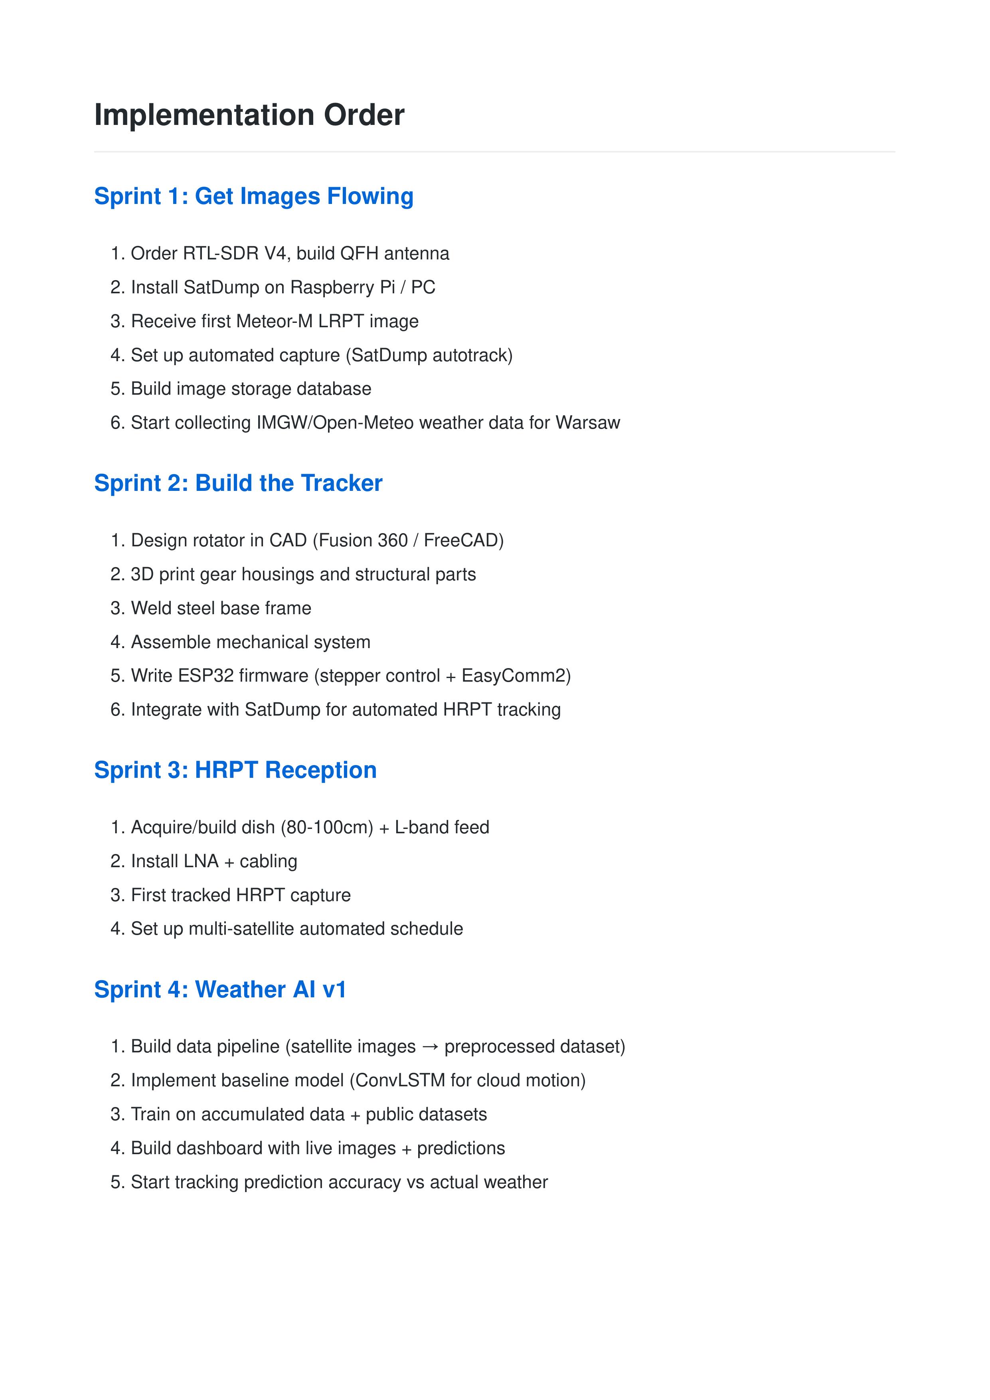
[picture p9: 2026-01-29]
radio-telescope-plan-images/page-11.jpg

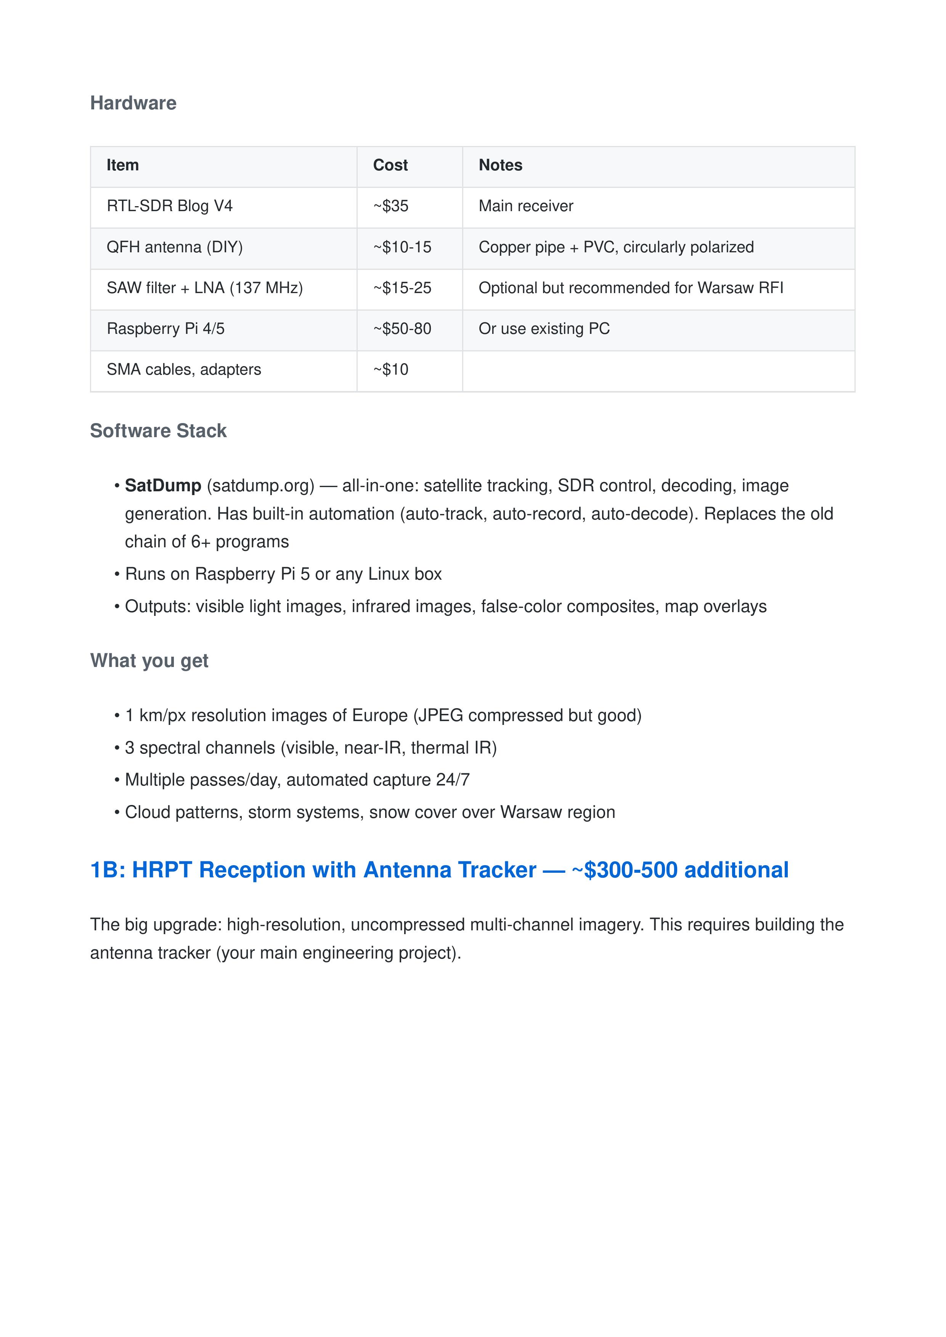
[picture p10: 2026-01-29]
radio-telescope-plan-images/page-02.jpg

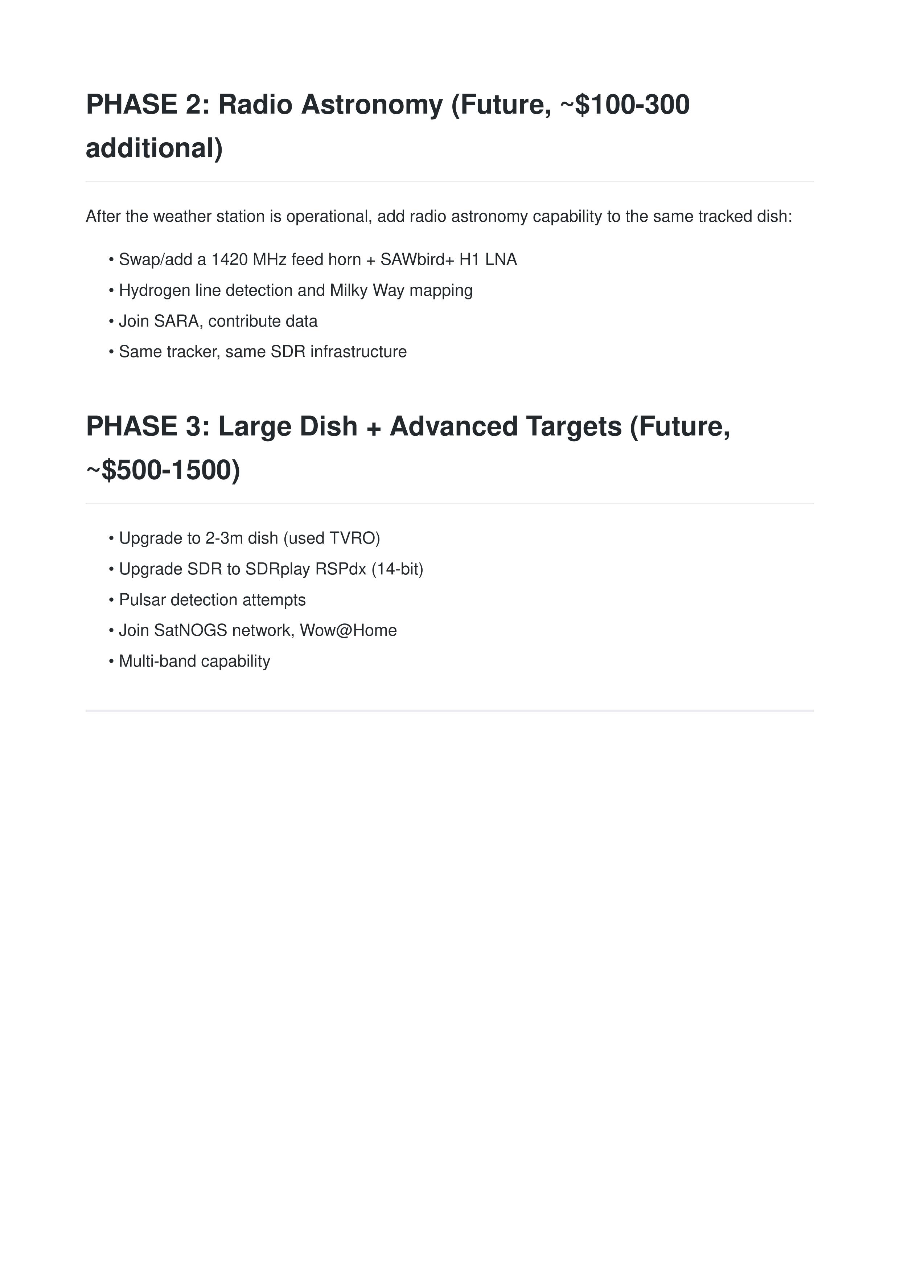
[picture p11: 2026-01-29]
radio-telescope-plan-images/page-09.jpg

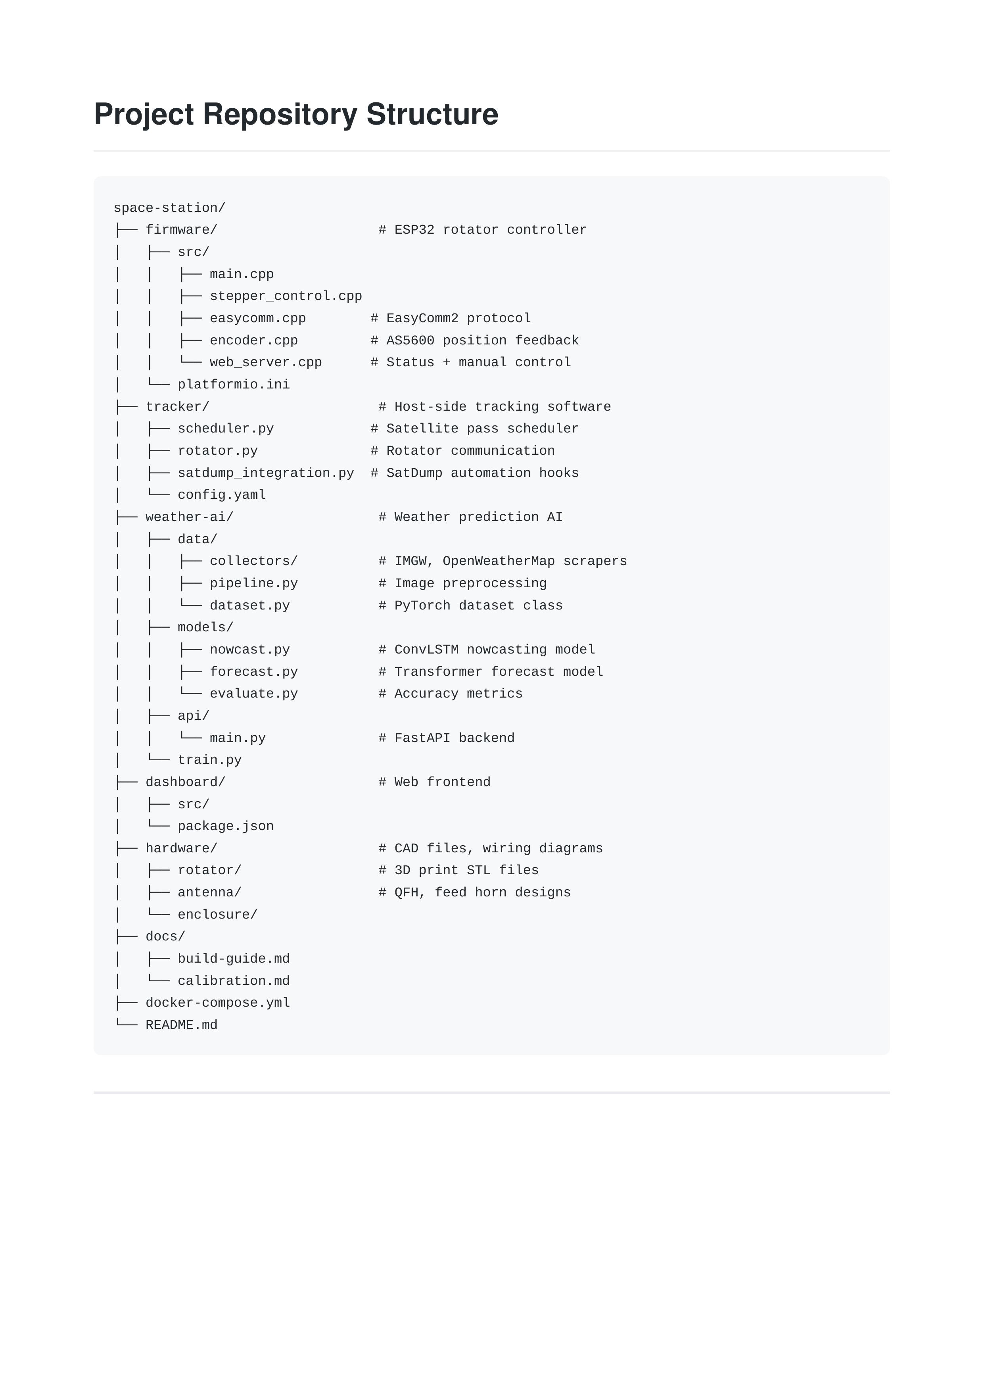
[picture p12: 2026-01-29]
radio-telescope-plan-images/page-10.jpg

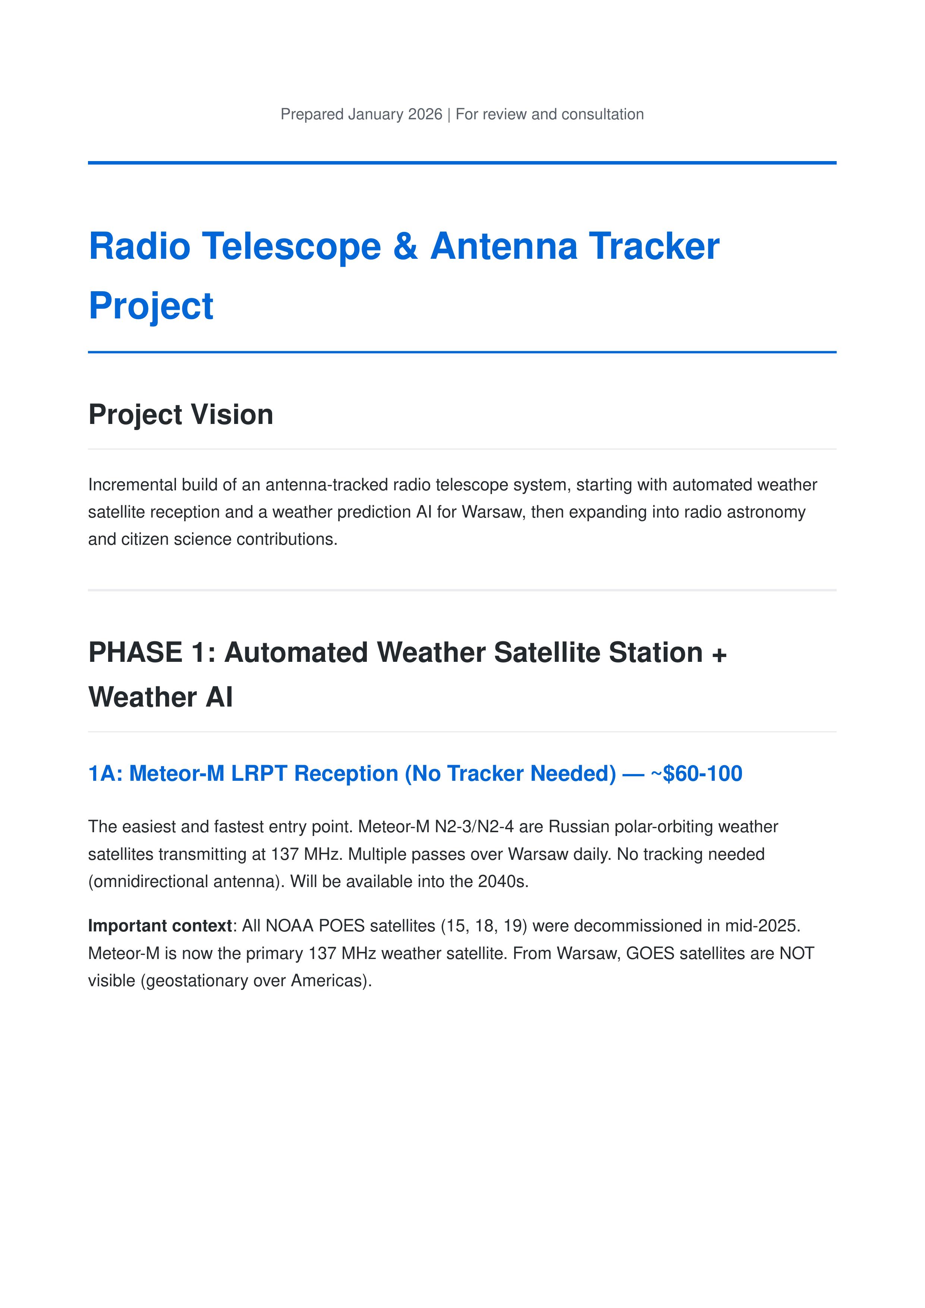
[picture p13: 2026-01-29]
radio-telescope-plan-images/page-01.jpg

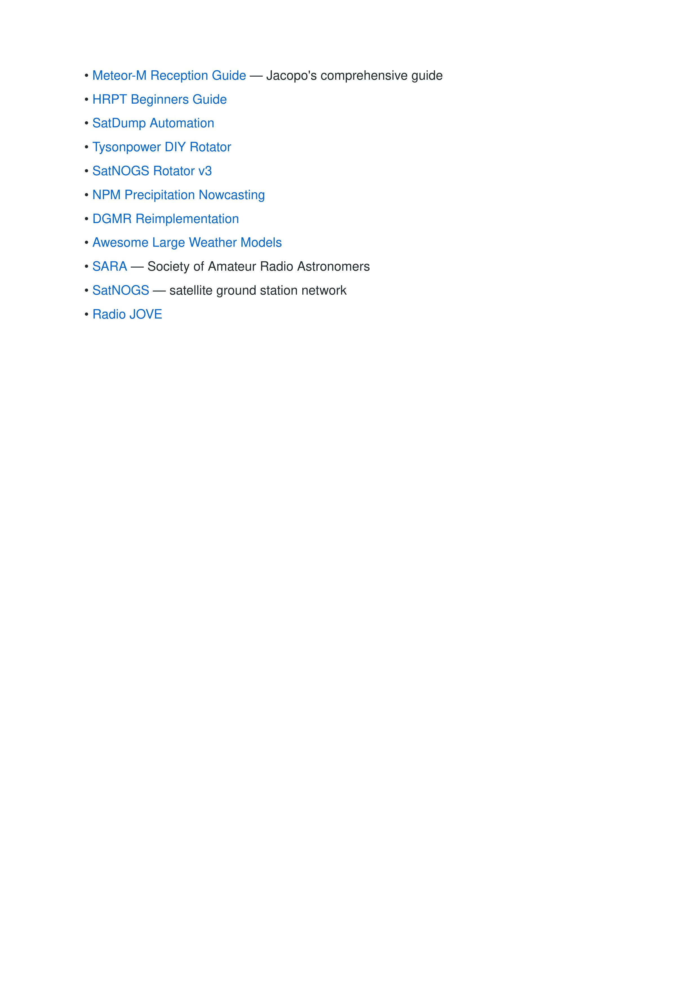
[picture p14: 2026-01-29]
radio-telescope-plan-images/page-13.jpg

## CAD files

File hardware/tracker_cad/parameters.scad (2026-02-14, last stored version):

// ============================================================
// Space Station Antenna Tracker - Shared Parameters
// ============================================================
// All dimensions in mm unless noted otherwise.
// Designed for Ender 3 (220x220mm bed) printing in PETG.
// ============================================================

// --- Print tolerances ---
// Adjust these based on your printer's calibration
tol         = 0.3;    // General clearance tolerance
press_tol   = 0.15;   // Press-fit tolerance (tighter)
loose_tol   = 0.5;    // Loose fit (moving parts)

// Layer height for calculations (typical PETG)
layer_h     = 0.2;

// --- Bearings ---
// 608ZZ (skateboard bearing)
b608_id     = 8;
b608_od     = 22;
b608_h      = 7;

// 6001ZZ (main shaft bearing)
b6001_id    = 12;
b6001_od    = 28;
b6001_h     = 8;

// 51107 thrust bearing (AZ axis)
bt51107_id  = 35;
bt51107_od  = 52;
bt51107_h   = 12;

// --- Steel rods ---
rod_dia     = 8;       // EL pivot shafts

// --- NEMA 17 stepper ---
nema17_face     = 42.3;
nema17_hole_sp  = 31;      // Hole center-to-center spacing
nema17_hole_dia = 3;       // M3 mounting holes
nema17_boss_dia = 22;      // Center boss diameter
nema17_boss_h   = 2;       // Center boss height
nema17_shaft_d  = 5;       // Shaft diameter
nema17_shaft_l  = 24;      // Shaft length
nema17_body_l   = 40;      // Motor body length (40mm variant)

// --- Worm gear parameters ---
// Module 1, pressure angle 20 deg
gear_module     = 1;       // Gear module (tooth size)
pressure_angle  = 20;      // Standard pressure angle

// Azimuth worm gear
az_worm_teeth   = 80;      // Worm wheel teeth (= gear ratio for single-start)
az_worm_starts  = 1;       // Single-start worm (self-locking)
az_worm_length  = 30;      // Worm screw length
az_worm_dia     = 12;      // Worm pitch diameter

// Elevation worm gear
el_worm_teeth   = 60;
el_worm_starts  = 1;
el_worm_length  = 25;
el_worm_dia     = 12;

// --- Gear derived dimensions ---
az_wheel_pitch_d = az_worm_teeth * gear_module;  // 80mm pitch dia
az_wheel_outer_d = az_wheel_pitch_d + 2 * gear_module;  // 82mm
el_wheel_pitch_d = el_worm_teeth * gear_module;  // 60mm pitch dia
el_wheel_outer_d = el_wheel_pitch_d + 2 * gear_module;  // 62mm

// Worm pitch = pi * module * starts
az_worm_pitch   = PI * gear_module * az_worm_starts;  // 3.14mm
el_worm_pitch   = PI * gear_module * el_worm_starts;

// --- Structural dimensions ---
wall_thick      = 4;       // Minimum wall thickness for PETG structural parts
wall_thick_heavy = 6;      // Heavy-duty walls (load-bearing)

// AZ base
az_base_dia     = 160;     // Base plate outer diameter
az_base_h       = 15;      // Base plate height
az_turntable_dia = 140;    // Turntable plate diameter
az_turntable_h  = 12;      // Turntable height
az_column_dia   = 50;      // Central column connecting AZ to EL
az_column_h     = 80;      // Column height

// EL yoke
el_yoke_width   = 180;     // Distance between yoke arms (outer)
el_yoke_arm_w   = 30;      // Yoke arm width (cross-section)
el_yoke_arm_h   = 200;     // Yoke arm height
el_yoke_thick   = 25;      // Yoke arm thickness

// Dish interface
dish_clamp_max_dia = 850;  // Max dish rim diameter
dish_clamp_min_dia = 550;  // Min dish rim diameter
dish_clamp_width   = 40;   // Clamp width
dish_rim_thick     = 3;    // Dish rim material thickness (typical sat dish)

// Feed arm
feed_arm_length = 400;     // Approximate focal length of 60-80cm offset dish
feed_arm_dia    = 25;      // Feed arm tube outer diameter

// LNB holder (standard 40mm LNB neck)
lnb_neck_dia    = 40;
lnb_neck_tol    = 1;       // Extra clearance for snap-fit

// --- Fasteners ---
// Heat-set insert holes (for M3, M4, M5)
m3_insert_hole  = 4.0;     // Hole for M3 heat-set insert
m3_insert_depth = 5;
m4_insert_hole  = 5.0;
m4_insert_depth = 6;
m5_insert_hole  = 6.4;
m5_insert_depth = 7;

// Through-holes
m3_through      = 3.4;
m4_through      = 4.5;
m5_through      = 5.5;
m8_through      = 8.5;

// Counterbore for socket head cap screws
m3_cbore_dia    = 6;
m3_cbore_depth  = 3.5;
m4_cbore_dia    = 8;
m4_cbore_depth  = 4.5;
m5_cbore_dia    = 10;
m5_cbore_depth  = 5.5;

// --- AS5600 encoder ---
as5600_board_w  = 20;      // Typical breakout board width
as5600_board_l  = 25;
as5600_board_h  = 2;
as5600_magnet_d = 6;       // Diametral magnet diameter
as5600_magnet_h = 3;       // Magnet height
as5600_sense_dist = 2;     // Air gap between magnet and sensor

// --- Electronics ---
rpi4_w          = 85;
rpi4_l          = 56;
rpi4_h          = 20;      // With heatsink
rpi4_hole_sp_w  = 58;      // Mounting hole spacing (width)
rpi4_hole_sp_l  = 49;      // Mounting hole spacing (length)

// TMC2209 driver board (StepStick form factor)
tmc_w           = 15.3;
tmc_l           = 20.3;
tmc_h           = 15;      // With heatsink

// --- Ender 3 build volume constraint ---
max_print_x     = 220;
max_print_y     = 220;
max_print_z     = 250;

// --- Helper ---
$fn = 64;  // Default facets for circles (increase for final render)

// Tiny value for clean boolean operations
eps = 0.01;

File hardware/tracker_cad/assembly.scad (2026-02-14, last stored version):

// ============================================================
// SPACE STATION - Full Tracker Assembly
// ============================================================
// Complete view of all 3D printed parts + hardware in position.
// Use this to verify fit and visualize the complete tracker.
//
// Render in OpenSCAD: F5 for preview, F6 for full render
// Recommend: View → Animate for exploded view
// ============================================================

include <parameters.scad>;
use <gears.scad>;
use <az_base.scad>;
use <el_yoke.scad>;
use <dish_clamp.scad>;
use <feed_bracket.scad>;
use <electronics_box.scad>;

// === Assembly configuration ===
explode = 0;             // Set 0-30 for exploded view spacing (mm)
show_dish = true;        // Show phantom dish outline
show_hardware = true;    // Show bearings, rods, motors (as phantoms)
show_electronics = true; // Show electronics box

// Current dish pointing (for visualization)
dish_az = 0;             // Azimuth angle (degrees)
dish_el = 45;            // Elevation angle (degrees)


// === ASSEMBLY ===

module full_assembly() {

    // ---- AZ BASE (stationary) ----
    color("DimGray", 0.9) {
        az_base_half();
        mirror([0, 1, 0]) az_base_half();
    }

    // Thrust bearing (phantom)
    if (show_hardware) {
        color("Silver", 0.5)
            translate([0, 0, az_base_h - bt51107_h/2])
            difference() {
                cylinder(d = bt51107_od, h = bt51107_h, $fn = 48);
                translate([0, 0, -eps])
                    cylinder(d = bt51107_id, h = bt51107_h + 2 * eps, $fn = 48);
            }
    }

    // ---- AZ TURNTABLE (rotates) ----
    rotate([0, 0, dish_az]) {

        translate([0, 0, az_base_h + explode]) {
            color("SteelBlue", 0.9) {
                az_turntable_half();
                mirror([0, 1, 0]) az_turntable_half();
            }

            // AZ Worm Wheel
            color("Gold", 0.8)
                translate([0, 0, -3])
                az_worm_wheel_printable();
        }

        // AZ Column (part of turntable, rises up)
        turntable_top = az_base_h + az_turntable_h + explode;

        // ---- AZ MOTOR + WORM ----
        if (show_hardware) {
            motor_z = az_base_h + 6;  // Worm center height
            worm_wheel_r = az_wheel_pitch_d / 2;
            worm_center_x = worm_wheel_r + az_worm_dia/2;

            // Motor body (phantom NEMA 17)
            color("DarkSlateGray", 0.4)
                translate([worm_center_x, 0, motor_z])
                rotate([0, 90, 0])
                translate([0, 0, 5]) {
                    // Motor body
                    cube([nema17_face, nema17_face, nema17_body_l], center = true);
                }

            // Worm screw
            color("Orange", 0.9)
                translate([worm_center_x, 0, motor_z])
                rotate([0, -90, 0])
                translate([0, 0, -az_worm_length/2])
                az_worm_printable();
        }

        // AZ Motor bracket
        color("Tomato", 0.8)
            translate([az_wheel_pitch_d/2 + az_worm_dia/2 + 8, 0, az_base_h])
            az_motor_bracket();

        // ---- EL YOKE ----
        yoke_base_z = turntable_top + az_column_h + explode * 2;

        translate([0, 0, yoke_base_z]) {

            // Yoke base
            color("CornflowerBlue", 0.9)
                el_yoke_base();

            base_h_local = 20;  // el_yoke_base height
            arm_x = arm_spacing_inner/2 + arm_thickness/2;

            // Right arm (worm wheel side)
            color("CadetBlue", 0.9) {
                translate([arm_x, 0, base_h_local + explode])
                    el_yoke_arm_lower(mirror_side = false);
                translate([arm_x, 0, base_h_local + arm_height/2 + explode * 2])
                    el_yoke_arm_upper(mirror_side = false);
            }

            // Left arm (mirror)
            color("CadetBlue", 0.9) {
                translate([-arm_x, 0, base_h_local + explode])
                    el_yoke_arm_lower(mirror_side = true);
                translate([-arm_x, 0, base_h_local + arm_height/2 + explode * 2])
                    el_yoke_arm_upper(mirror_side = true);
            }

            // ---- PIVOT ROD (8mm steel) ----
            pivot_abs_z = base_h_local + pivot_z;

            if (show_hardware) {
                color("Silver", 0.7)
                    translate([0, 0, pivot_abs_z])
                    rotate([0, 90, 0])
                    cylinder(d = rod_dia, h = arm_spacing_inner + arm_thickness * 2 + 20,
                             center = true, $fn = 24);
            }

            // ---- EL WORM WHEEL (on pivot rod) ----
            color("Gold", 0.8)
                translate([arm_x + arm_thickness/2 + 5, 0, pivot_abs_z])
                rotate([90, 0, 0])
                translate([0, 0, -5])
                el_worm_wheel_printable();

            // EL Motor bracket
            color("Tomato", 0.8)
                translate([arm_x + arm_thickness/2 + 2, 0, pivot_abs_z - 25])
                rotate([0, 0, 90])
                el_motor_bracket();

            // ---- EL MOTOR + WORM ----
            if (show_hardware) {
                el_motor_z = pivot_abs_z;
                el_worm_x = arm_x + arm_thickness/2 + el_wheel_pitch_d/2 + el_worm_dia/2 + 5;

                color("DarkSlateGray", 0.4)
                    translate([el_worm_x + 25, 0, el_motor_z])
                    rotate([0, -90, 0])
                    cube([nema17_face, nema17_face, nema17_body_l], center = true);

                color("Orange", 0.9)
                    translate([el_worm_x, 0, el_motor_z])
                    rotate([0, 90, 0])
                    translate([0, 0, -el_worm_length/2])
                    el_worm_printable();
            }

            // ---- DISH (rotating on EL axis) ----
            rotate([0, 0, 0])  // EL rotation would be around X axis at pivot
            translate([0, 0, pivot_abs_z]) {

                // Pivot clamps (2x, on rod)
                color("MediumSeaGreen", 0.9) {
                    translate([0, 0, 0])
                        rotate([0, 90, 0])
                        translate([-15, 0, -50])
                        pivot_clamp();
                    translate([0, 0, 0])
                        rotate([0, 90, 0])
                        translate([-15, 0, 20])
                        pivot_clamp();
                }

                // Dish clamps (2x)
                color("LimeGreen", 0.9) {
                    translate([-40, 30, 20 + explode])
                        rotate([dish_el - 90, 0, 0])
                        dish_clamp();
                    translate([40, 30, 20 + explode])
                        rotate([dish_el - 90, 0, 0])
                        dish_clamp();
                }

                // Phantom dish
                if (show_dish) {
                    dish_dia = 700;  // 70cm
                    color("White", 0.15)
                        translate([0, 0, 40])
                        rotate([dish_el - 90, 0, 0])
                        translate([0, 0, 100])  // Offset dish geometry
                        scale([1, 1, 0.15])
                        sphere(d = dish_dia, $fn = 32);
                }

                // Feed bracket (at focal point, approximate)
                color("Coral", 0.9)
                    translate([0, 0, 30])
                    rotate([dish_el - 90, 0, 0])
                    translate([0, -250, 0])  // Approximate focal distance
                    rotate([90, 0, 0]) {
                        feed_arm_clamp();
                        translate([35, 0, 0])
                            lnb_holder();
                    }
            }
        }

        // ---- ELECTRONICS BOX ----
        if (show_electronics) {
            color("DarkOliveGreen", 0.8)
                translate([0, -80, az_base_h + az_turntable_h + 20])
                electronics_box();
        }
    }
}


// ==== RENDER ====
full_assembly();
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

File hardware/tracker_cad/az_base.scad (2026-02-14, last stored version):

// ============================================================
// Azimuth Base and Turntable Assembly
// ============================================================
// Two main parts:
//   1. Base plate (stationary) - sits on tripod or pipe mount
//   2. Turntable (rotating) - carries the elevation yoke
//
// Each is split into 2 halves for Ender 3 bed (max 220mm).
// Halves are bolted together with M4 bolts.
//
// Bearing stack: 51107 thrust bearing + 608ZZ radial bearings
// for smooth rotation under dish load.
//
// Worm wheel is attached to turntable, driven by worm on motor.
// ============================================================

include <parameters.scad>;
use <gears.scad>;

// === AZIMUTH BASE PLATE (STATIONARY) ===

module az_base_half() {
    // One half of the base plate (print 2, bolt together)

    base_r = az_base_dia / 2;
    thrust_pocket_r = bt51107_od / 2 + tol;
    thrust_pocket_depth = bt51107_h / 2 + 1;  // Bearing sits halfway in each plate
    radial_pocket_r = b608_od / 2 + tol;

    difference() {
        union() {
            // Half-circle base plate
            linear_extrude(height = az_base_h) {
                difference() {
                    // Half circle (with flat edge for bolting)
                    intersection() {
                        circle(r = base_r);
                        translate([-base_r, 0])
                            square([base_r * 2, base_r + 1]);
                    }
                }
            }

            // Bolt flanges at the split line
            for (x = [-base_r * 0.6, base_r * 0.6]) {
                translate([x, -5, 0])
                    cylinder(d = 14, h = az_base_h, $fn = 24);
            }
        }

        // Thrust bearing pocket (center, top side)
        translate([0, 0, az_base_h - thrust_pocket_depth])
            cylinder(r = thrust_pocket_r, h = thrust_pocket_depth + eps, $fn = 64);

        // Radial bearing pockets (2x 608ZZ, symmetrically placed)
        for (a = [45, 135]) {
            rotate([0, 0, a])
                translate([bt51107_od/2 + 5, 0, az_base_h - b608_h - 1])
                    cylinder(r = radial_pocket_r, h = b608_h + 1 + eps, $fn = 48);
        }

        // Center hole for wiring
        translate([0, 0, -eps])
            cylinder(d = 20, h = az_base_h + 2 * eps, $fn = 32);

        // Bolt holes along split line (M4 through-holes)
        for (x = [-base_r * 0.6, base_r * 0.6]) {
            translate([x, -5, -eps])
                cylinder(d = m4_through, h = az_base_h + 2 * eps, $fn = 16);

            // Counterbore from bottom
            translate([x, -5, -eps])
                cylinder(d = m4_cbore_dia, h = m4_cbore_depth + eps, $fn = 16);
        }

        // Tripod mounting holes (1/4-20 UNC = 6.35mm, or M6)
        // 3 holes on a 100mm circle for camera tripod plate
        for (a = [30, 90, 150]) {
            rotate([0, 0, a])
                translate([50, 0, -eps])
                    cylinder(d = 6.5, h = az_base_h + 2 * eps, $fn = 24);
        }

        // Motor mounting cutout (one side, for worm approach)
        translate([base_r - 25, -nema17_face/2 - 5, -eps])
            cube([30, nema17_face + 10, az_base_h + 2 * eps]);
    }
}


// === AZIMUTH TURNTABLE (ROTATING) ===

module az_turntable_half() {
    // One half of the turntable (print 2, bolt together)

    tt_r = az_turntable_dia / 2;
    thrust_boss_r = bt51107_id / 2 - 1;
    thrust_boss_h = bt51107_h / 2 + 1;

    difference() {
        union() {
            // Half-circle turntable plate
            linear_extrude(height = az_turntable_h) {
                intersection() {
                    circle(r = tt_r);
                    translate([-tt_r, 0])
                        square([tt_r * 2, tt_r + 1]);
                }
            }

            // Center boss (sits inside thrust bearing)
            translate([0, 0, -thrust_boss_h])
                cylinder(r = thrust_boss_r, h = thrust_boss_h, $fn = 48);

            // Column base (connects to EL yoke)
            cylinder(d = az_column_dia, h = az_turntable_h + 20, $fn = 48);

            // Bolt flanges at split line
            for (x = [-tt_r * 0.6, tt_r * 0.6]) {
                translate([x, -5, 0])
                    cylinder(d = 14, h = az_turntable_h, $fn = 24);
            }
        }

        // Worm wheel mounting ring (the gear attaches here)
        // Ring of M3 holes for bolting worm wheel
        for (a = [0:45:180]) {
            rotate([0, 0, a])
                translate([az_wheel_pitch_d/2 - 10, 0, -eps]) {
                    cylinder(d = m3_through, h = az_turntable_h + 2 * eps, $fn = 16);
                }
        }

        // Center hole for wiring
        translate([0, 0, -thrust_boss_h - eps])
            cylinder(d = 16, h = az_turntable_h + thrust_boss_h + 30, $fn = 32);

        // Bolt holes along split line
        for (x = [-tt_r * 0.6, tt_r * 0.6]) {
            translate([x, -5, -eps])
                cylinder(d = m4_through, h = az_turntable_h + 2 * eps, $fn = 16);
        }

        // Column top mounting holes (for EL yoke attachment, M5)
        for (a = [0, 90, 180, 270]) {
            rotate([0, 0, a])
                translate([az_column_dia/2 - 8, 0, az_turntable_h + 10]) {
                    // Hole from side for bolt
                    rotate([0, 0, 0])
                        translate([0, 0, 0])
                        cylinder(d = m5_insert_hole, h = m5_insert_depth, $fn = 16);
                }
        }
    }
}


// === AZ WORM WHEEL (separate part, bolts to turntable) ===

module az_worm_wheel_printable() {
    // 80-tooth worm wheel for azimuth axis
    // Bolts to turntable via M3 holes on a ring

    worm_wheel(
        teeth = az_worm_teeth,      // 80
        mod = gear_module,          // 1
        face_width = 12,
        bore = az_column_dia + loose_tol * 2,  // Fits around column
        worm_dia = az_worm_dia,
        hub_dia = az_column_dia + 12,
        hub_h = 8,
        backlash = 0.2,
        set_screw = false,
        keyway = false
    );

    // Note: This gear has a large bore to fit around the turntable column.
    // It's bolted to the turntable rather than press-fit on a shaft.
}


// === AZ WORM SCREW ===

module az_worm_printable() {
    // Single-start worm for azimuth motor
    worm_screw(
        length = az_worm_length,    // 30mm
        pitch_dia = az_worm_dia,    // 12mm
        mod = gear_module,          // 1
        starts = az_worm_starts,    // 1 (self-locking)
        bore = nema17_shaft_d,      // 5mm (NEMA 17 shaft)
        backlash = 0.15,
        keyway = true
    );
}


// === AZ MOTOR BRACKET ===

module az_motor_bracket() {
    // NEMA 17 mount that attaches to the base plate
    // Positions the motor so the worm meshes with the wheel on the turntable

    bracket_w = nema17_face + 10;
    bracket_h = nema17_face + 10;
    bracket_thick = wall_thick_heavy;

    // Worm-to-wheel center distance
    center_dist = (az_wheel_pitch_d + az_worm_dia) / 2;

    difference() {
        union() {
            // Vertical plate (motor mounts here)
            translate([-bracket_w/2, 0, 0])
                cube([bracket_w, bracket_thick, bracket_h]);

            // Base feet (bolt to base plate)
            translate([-bracket_w/2, 0, 0])
                cube([bracket_w, 30, wall_thick]);

            // Gussets for rigidity
            for (x = [-bracket_w/2, bracket_w/2 - wall_thick]) {
                translate([x, bracket_thick, 0])
                    linear_extrude(height = wall_thick)
                    polygon([[0,0], [0, 20], [20, 0]]);
            }
        }

        // NEMA 17 mounting holes
        motor_center_z = bracket_h / 2;
        translate([0, -eps, motor_center_z])
            rotate([-90, 0, 0]) {
                // Shaft hole
                cylinder(d = nema17_boss_dia + 2, h = bracket_thick + 2 * eps, $fn = 32);

                // Mounting bolts (31mm spacing, M3)
                for (dx = [-1, 1], dy = [-1, 1]) {
                    translate([dx * nema17_hole_sp/2, dy * nema17_hole_sp/2, 0])
                        cylinder(d = m3_through, h = bracket_thick + 2 * eps, $fn = 16);
                }
            }

        // Base bolt holes (M4 to base plate)
        for (x = [-bracket_w/4, bracket_w/4]) {
            translate([x, 15, -eps])
                cylinder(d = m4_through, h = wall_thick + 2 * eps, $fn = 16);
        }
    }
}


// === PREVIEW ===

// Uncomment one to preview:

// Full AZ assembly (exploded)
// color("DarkSlateGray") az_base_half();
// color("DarkSlateGray") mirror([0, 1, 0]) az_base_half();
// color("SteelBlue") translate([0, 0, az_base_h + 2]) az_turntable_half();
// color("SteelBlue") translate([0, 0, az_base_h + 2]) mirror([0, 1, 0]) az_turntable_half();
// color("Gold") translate([0, 0, az_base_h]) az_worm_wheel_printable();
// color("Orange") translate([80, 0, az_base_h + 6]) rotate([0, 90, 0]) az_worm_printable();
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

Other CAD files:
hardware/tracker_cad/dish_clamp.scad
hardware/tracker_cad/el_yoke.scad
hardware/tracker_cad/electronics_box.scad
hardware/tracker_cad/feed_bracket.scad
hardware/tracker_cad/gears.scad

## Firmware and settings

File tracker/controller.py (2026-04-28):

"""Two-axis stepper controller for the alt-az antenna tracker.

Drives the Waveshare Stepper Motor HAT (B) on a Raspberry Pi 4B via lgpio.
On dev machines without lgpio (or when --sim is requested), a no-op GPIO
shim is used so position math, CLI, and tests still run.
"""

from __future__ import annotations

import math
import threading
from .hr8825 import HR8825  # Waveshare reference driver
import time
from dataclasses import dataclass, field
from pathlib import Path
from typing import Any

import click
import yaml
from rich.console import Console
from rich.table import Table

try:
    import lgpio  # type: ignore
    _HAS_LGPIO = True
except ImportError:
    lgpio = None  # type: ignore
    _HAS_LGPIO = False


# Pulse / setup timings for typical step/dir drivers (TMC2209-class).
_STEP_PULSE_S = 200e-6      # STEP high pulse width
_DIR_SETUP_S = 5e-6       # DIR-to-STEP setup time
_MIN_STEP_INTERVAL_S = 1e-4  # 100 µs floor between rising edges


# --------------------------------------------------------------------------- #
# GPIO backends
# --------------------------------------------------------------------------- #


class _LgpioBackend:
    """Thin wrapper over lgpio so the rest of the module is backend-agnostic."""

    mode = "real"

    def __init__(self, chip: int = 0) -> None:
        self._handle = lgpio.gpiochip_open(chip)
        self._claimed: set[int] = set()

    def claim_output(self, pin: int, initial: int = 0) -> None:
        if pin in self._claimed:
            return
        lgpio.gpio_claim_output(self._handle, pin, initial)
        self._claimed.add(pin)

    def write(self, pin: int, level: int) -> None:
        lgpio.gpio_write(self._handle, pin, level)

    def close(self) -> None:
        if self._handle is not None:
            try:
                lgpio.gpiochip_close(self._handle)
            finally:
                self._handle = None


class _SimGpio:
    """Position-state-only GPIO. Records writes, performs no I/O."""

    mode = "sim"

    def __init__(self) -> None:
        self.levels: dict[int, int] = {}

    def claim_output(self, pin: int, initial: int = 0) -> None:
        self.levels[pin] = initial

    def write(self, pin: int, level: int) -> None:
        self.levels[pin] = level

    def close(self) -> None:
        self.levels.clear()


# --------------------------------------------------------------------------- #
# Single-axis controller
# --------------------------------------------------------------------------- #


@dataclass
class StepperAxis:
    name: str
    step_pin: int
    dir_pin: int
    enable_pin: int
    steps_per_rev: int
    microstepping: int
    gear_ratio: float
    max_speed: float          # deg/s
    acceleration: float       # deg/s²
    min_angle: float
    max_angle: float
    gpio: Any = None
    position_deg: float = 0.0
    enabled: bool = False
    _stop_flag: threading.Event = field(default_factory=threading.Event, repr=False)
    _lock: threading.Lock = field(default_factory=threading.Lock, repr=False)

    def __post_init__(self) -> None:
        # Real-hardware mode: use Waveshare HR8825 driver. Sim mode: keep _SimGpio for state-only updates.
        self._driver = None
        if self.gpio is None or isinstance(self.gpio, _SimGpio):
            if self.gpio is None:
                self.gpio = _SimGpio()
            return
        # Pick mode pins per axis name (matches config.yaml convention)
        mode_pins = (16, 17, 20) if self.name == "azimuth" else (21, 22, 27)
        self._driver = HR8825(dir_pin=self.dir_pin, step_pin=self.step_pin,
                              enable_pin=self.enable_pin, mode_pins=mode_pins)
        self._driver.SetMicroStep("softward", "fullstep")

    # ---- conversions ----

    @property
    def total_steps_per_rev(self) -> int:
        return int(self.steps_per_rev * self.microstepping * self.gear_ratio)

    @property
    def degrees_per_step(self) -> float:
        return 360.0 / self.total_steps_per_rev

    @property
    def position_steps(self) -> int:
        return int(round(self.position_deg / self.degrees_per_step))

    # ---- enable line ----

    def enable(self) -> None:
        if self._driver is not None:
            self._driver.digital_write(self.enable_pin, 1)  # Waveshare HAT B: active-HIGH
        else:
            self.gpio.write(self.enable_pin, 1)
        self.enabled = True

    def disable(self) -> None:
        if self._driver is not None:
            self._driver.digital_write(self.enable_pin, 0)
        else:
            self.gpio.write(self.enable_pin, 0)
        self.enabled = False

    # ---- motion primitives ----

    def step(self, direction: int) -> None:
        if direction not in (+1, -1):
            raise ValueError("direction must be +1 or -1")
        if self._driver is not None:
            d = "forward" if direction > 0 else "backward"
            self._driver.TurnStep(Dir=d, steps=1, stepdelay=0.005)
        self.position_deg += direction * self.degrees_per_step

    def stop(self) -> None:
        self._stop_flag.set()

    def move_steps(self, n_steps: int, direction: int) -> None:
        """Move n_steps. Real hw: HR8825.TurnStep (constant rate). Sim: just bump state."""
        if n_steps <= 0:
            return
        with self._lock:
            self._stop_flag.clear()
            if not self.enabled:
                self.enable()
            if self._driver is not None:
                d = "forward" if direction > 0 else "backward"
                # stepdelay is half-period each side; pick from max_speed (steps/s)
                v_max_steps = max(self.max_speed / self.degrees_per_step, 1.0)
                stepdelay = 0.5 / v_max_steps
                self._driver.TurnStep(Dir=d, steps=n_steps, stepdelay=stepdelay)
                self.position_deg += direction * self.degrees_per_step * n_steps
            else:
                # sim path — instantaneous bookkeeping
                self.position_deg += direction * self.degrees_per_step * n_steps

    def goto_deg(self, target_deg: float) -> None:
        target = max(self.min_angle, min(self.max_angle, target_deg))
        delta_deg = target - self.position_deg
        n_steps = int(round(abs(delta_deg) / self.degrees_per_step))
        if n_steps == 0:
            return
        direction = +1 if delta_deg > 0 else -1
        self.move_steps(n_steps, direction)
        # Snap to commanded value to avoid rounding drift across many moves.
        self.position_deg = target

    def to_dict(self) -> dict[str, Any]:
        return {
            "name": self.name,
            "position_deg": round(self.position_deg, 4),
            "position_steps": self.position_steps,
            "enabled": self.enabled,
            "min_angle": self.min_angle,
            "max_angle": self.max_angle,
            "max_speed": self.max_speed,
            "degrees_per_step": round(self.degrees_per_step, 6),
        }


# --------------------------------------------------------------------------- #
# Two-axis orchestration
# --------------------------------------------------------------------------- #


class AntennaTracker:
    def __init__(
        self,
        azimuth: StepperAxis,
        elevation: StepperAxis,
        config: dict[str, Any],
        gpio: Any,
    ) -> None:
        self.az = azimuth
        self.el = elevation
        self.config = config
        self.gpio = gpio

    # ---- factory ----

    @classmethod
    def from_config(
        cls,
        path: str | Path,
        gpio_backend: str = "auto",
    ) -> AntennaTracker:
        cfg_path = Path(path)
        with cfg_path.open("r", encoding="utf-8") as fh:
            cfg = yaml.safe_load(fh)

        tracker_cfg = cfg["tracker"]
        gpio = cls._make_gpio(gpio_backend)

        az_cfg = tracker_cfg["azimuth"]
        el_cfg = tracker_cfg["elevation"]
        az = cls._build_axis("azimuth", az_cfg, gpio)
        el = cls._build_axis("elevation", el_cfg, gpio)
        return cls(az, el, cfg, gpio)

    @staticmethod
    def _make_gpio(backend: str) -> Any:
        if backend == "sim":
            return _SimGpio()
        if backend == "real":
            if not _HAS_LGPIO:
                raise RuntimeError("lgpio not available — install lgpio or use sim mode")
            return _LgpioBackend()
        # auto
        if _HAS_LGPIO:
            try:
                return _LgpioBackend()
            except Exception:
                return _SimGpio()
        return _SimGpio()

    @staticmethod
    def _build_axis(name: str, c: dict[str, Any], gpio: Any) -> StepperAxis:
        return StepperAxis(
            name=name,
            step_pin=int(c["step_pin"]),
            dir_pin=int(c["dir_pin"]),
            enable_pin=int(c["enable_pin"]),
            steps_per_rev=int(c["steps_per_rev"]),
            microstepping=int(c["microstepping"]),
            gear_ratio=float(c["gear_ratio"]),
            max_speed=float(c["max_speed"]),
            acceleration=float(c["acceleration"]),
            min_angle=float(c["min_angle"]),
            max_angle=float(c["max_angle"]),
            gpio=gpio,
        )

    # ---- motion ----

    def goto(self, az_deg: float, el_deg: float) -> None:
        threads = [
            threading.Thread(target=self.az.goto_deg, args=(az_deg,), daemon=True),
            threading.Thread(target=self.el.goto_deg, args=(el_deg,), daemon=True),
        ]
        for t in threads:
            t.start()
        for t in threads:
            t.join()

    def home(self) -> None:
        """Naive home: drive both axes to 0,0 in software (no limit switch yet)."""
        self.goto(self.az.min_angle, self.el.min_angle)
        self.az.position_deg = 0.0
        self.el.position_deg = 0.0

    def park(self) -> None:
        tcfg = self.config.get("tracker", {})
        az_park = float(tcfg.get("park_azimuth", 0.0))
        el_park = float(tcfg.get("park_elevation", 90.0))
        self.goto(az_park, el_park)

    def stop(self) -> None:
        self.az.stop()
        self.el.stop()

    def enable_all(self) -> None:
        self.az.enable()
        self.el.enable()

    def disable_all(self) -> None:
        self.az.disable()
        self.el.disable()

    def status(self) -> dict[str, Any]:
        return {
            "az": self.az.to_dict(),
            "el": self.el.to_dict(),
            "mode": getattr(self.gpio, "mode", "unknown"),
        }

    def close(self) -> None:
        self.disable_all()
        self.gpio.close()


# --------------------------------------------------------------------------- #
# CLI
# --------------------------------------------------------------------------- #


_DEFAULT_CONFIG = "tracker/config.yaml"


def _backend(sim: bool) -> str:
    return "sim" if sim else "auto"


def _load(config: str, sim: bool) -> AntennaTracker:
    return AntennaTracker.from_config(config, gpio_backend=_backend(sim))


def _render_status(tracker: AntennaTracker) -> None:
    s = tracker.status()
    console = Console()
    table = Table(title=f"Antenna tracker status (mode={s['mode']})")
    table.add_column("axis", style="bold cyan")
    table.add_column("position (deg)", justify="right")
    table.add_column("position (steps)", justify="right")
    table.add_column("enabled", justify="center")
    table.add_column("range", justify="right")
    table.add_column("deg/step", justify="right")
    for key in ("az", "el"):
        a = s[key]
        table.add_row(
            a["name"],
            f"{a['position_deg']:.4f}",
            f"{a['position_steps']}",
            "yes" if a["enabled"] else "no",
            f"[{a['min_angle']:.0f}, {a['max_angle']:.0f}]",
            f"{a['degrees_per_step']:.6f}",
        )
    console.print(table)


@click.group()
@click.option("--config", default=_DEFAULT_CONFIG, show_default=True,
              help="Path to tracker config YAML.")
@click.option("--sim", is_flag=True, help="Force simulation GPIO backend.")
@click.pass_context
def cli(ctx: click.Context, config: str, sim: bool) -> None:
    """Alt-az antenna tracker control."""
    ctx.ensure_object(dict)
    ctx.obj["config"] = config
    ctx.obj["sim"] = sim


@cli.command()
@click.pass_context
def status(ctx: click.Context) -> None:
    """Show current axis state."""
    tracker = _load(ctx.obj["config"], ctx.obj["sim"])
    _render_status(tracker)
    tracker.close()


@cli.command()
@click.argument("az", type=float)
@click.argument("el", type=float)
@click.pass_context
def goto(ctx: click.Context, az: float, el: float) -> None:
    """Move to (AZ, EL) in degrees."""
    tracker = _load(ctx.obj["config"], ctx.obj["sim"])
    tracker.enable_all()
    tracker.goto(az, el)
    _render_status(tracker)
    tracker.close()


@cli.command()
@click.pass_context
def home(ctx: click.Context) -> None:
    """Home both axes."""
    tracker = _load(ctx.obj["config"], ctx.obj["sim"])
    tracker.enable_all()
    tracker.home()
    _render_status(tracker)
    tracker.close()


@cli.command()
@click.pass_context
def park(ctx: click.Context) -> None:
    """Move to park position."""
    tracker = _load(ctx.obj["config"], ctx.obj["sim"])
    tracker.enable_all()
    tracker.park()
    _render_status(tracker)
    tracker.close()


@cli.command()
@click.option("--motor", type=click.Choice(["az", "el"]), required=True)
@click.option("--count", type=int, required=True, help="Number of microsteps.")
@click.option("--dir", "direction", type=click.Choice(["cw", "ccw"]), default="cw",
              show_default=True)
@click.pass_context
def step(ctx: click.Context, motor: str, count: int, direction: str) -> None:
    """Pulse N microsteps on one motor."""
    tracker = _load(ctx.obj["config"], ctx.obj["sim"])
    axis = tracker.az if motor == "az" else tracker.el
    axis.enable()
    axis.move_steps(count, +1 if direction == "cw" else -1)
    _render_status(tracker)
    tracker.close()


@cli.command()
@click.pass_context
def stop(ctx: click.Context) -> None:
    """Disable drivers and stop motion."""
    tracker = _load(ctx.obj["config"], ctx.obj["sim"])
    tracker.stop()
    tracker.disable_all()
    _render_status(tracker)
    tracker.close()


if __name__ == "__main__":
    cli(obj={})

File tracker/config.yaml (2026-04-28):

site:
  name: Warsaw
  latitude: 52.2297
  longitude: 21.0122
  elevation: 100
tracker:
  type: alt-az
  driver: waveshare_hat_b
  park_azimuth: 0.0
  park_elevation: 90.0
  position_tolerance: 0.1
  tracking_interval: 0.5
  azimuth:
    gear_ratio: 1
    steps_per_rev: 200
    microstepping: 32
    min_angle: 0.0
    max_angle: 360.0
    max_speed: 6.0
    acceleration: 3.0
    step_pin: 19
    dir_pin: 13
    enable_pin: 12
    home_switch_pin: 5
    home_switch_enabled: false
    home_offset: 0.0
  elevation:
    gear_ratio: 1
    steps_per_rev: 200
    microstepping: 32
    min_angle: 0.0
    max_angle: 90.0
    max_speed: 6.0
    acceleration: 3.0
    step_pin: 18
    dir_pin: 24
    enable_pin: 4
    home_switch_pin: 6
    home_switch_enabled: false
    home_offset: 0.0
bands:
  l_band:
    enabled: false
    sample_rate: 2400000
    gain: 40.0
    freq_min: 1525000000
    freq_max: 1559000000
    notes: Direct RTL-SDR, no LO/LNB. Inmarsat downlink band.
  ku_band:
    enabled: false
    lnb:
      model: Inverto IDLB-SINL40
      type: PLL
      lo_low: 9750000000
      lo_high: 10600000000
      switch_freq: 11700000000
    gpio:
      power_pin: 23
      voltage_select_pin: 25
      tone_pin: 26
    notes: Dish + LNB. Phase 4 maser detection target.
targets:
  alphasat_25e:
    name: "Inmarsat 4F2 / Alphasat (25\xB0E)"
    sat_longitude: 25.0
    band: l_band
  inmarsat_4f3_98w:
    name: "Inmarsat 4F3 (98\xB0W)"
    sat_longitude: -98.0
    band: l_band
  inmarsat_3f5_54w:
    name: "Inmarsat 3F5 (54\xB0W)"
    sat_longitude: -54.0
    band: l_band
  inmarsat_f1_143_5e:
    name: "Inmarsat F1 (143.5\xB0E)"
    sat_longitude: 143.5
    band: l_band
sniffer:
  enabled: false
  binary_path: vendor/inmarsat-sniffer/build/inmarsat-sniffer
  feed_udp_host: 127.0.0.1
  feed_udp_port: 5000
  skip_c_channel: true
  web_port: 8888
  default_target: alphasat_25e

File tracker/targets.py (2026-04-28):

"""Geostationary look-angle math + named target presets for the antenna tracker.

Pure math + dataclasses + click CLI. No I/O beyond reading the YAML config.
"""
from __future__ import annotations

import math
from dataclasses import dataclass
from pathlib import Path

import click
import yaml
from rich.console import Console
from rich.table import Table

# Earth radius (km, WGS-84 equatorial) over GEO orbit radius (km).
_EARTH_RADIUS_KM = 6378.137
_GEO_RADIUS_KM = 42164.17
_R_RATIO = _EARTH_RADIUS_KM / _GEO_RADIUS_KM  # ≈ 0.1512

DEFAULT_CONFIG_PATH = Path("tracker/config.yaml")


@dataclass
class Target:
    key: str
    name: str
    sat_longitude: float  # deg, east positive
    band: str
    az: float | None = None  # deg true, clockwise from north, [0, 360)
    el: float | None = None  # deg, [-90, 90]


def geostationary_azel(
    site_lat_deg: float, site_lon_deg: float, sat_lon_deg: float
) -> tuple[float, float]:
    """Look-angle (azimuth_deg, elevation_deg) to a GEO sat from a ground site.

    Spherical Earth, Earth radius 6378.137 km, GEO orbit radius 42164.17 km.
    Azimuth measured clockwise from true north in [0, 360); elevation in
    [-90, 90] (negative means below horizon).

    Uses an ECEF → ENU vector transform so the result is correct in both
    hemispheres and for both east- and west-of-site satellites.
    """
    phi = math.radians(site_lat_deg)
    lam_s = math.radians(site_lon_deg)
    lam_t = math.radians(sat_lon_deg)

    cos_phi = math.cos(phi)
    sin_phi = math.sin(phi)
    cos_ls = math.cos(lam_s)
    sin_ls = math.sin(lam_s)

    # Site position in ECEF (spherical Earth).
    sx = _EARTH_RADIUS_KM * cos_phi * cos_ls
    sy = _EARTH_RADIUS_KM * cos_phi * sin_ls
    sz = _EARTH_RADIUS_KM * sin_phi

    # GEO satellite position in ECEF (equatorial plane).
    tx = _GEO_RADIUS_KM * math.cos(lam_t)
    ty = _GEO_RADIUS_KM * math.sin(lam_t)
    tz = 0.0

    dx, dy, dz = tx - sx, ty - sy, tz - sz

    # ECEF → local ENU (East, North, Up) at the site.
    east = -sin_ls * dx + cos_ls * dy
    north = -sin_phi * cos_ls * dx - sin_phi * sin_ls * dy + cos_phi * dz
    up = cos_phi * cos_ls * dx + cos_phi * sin_ls * dy + sin_phi * dz

    az_rad = math.atan2(east, north) % (2.0 * math.pi)
    el_rad = math.atan2(up, math.sqrt(east * east + north * north))

    return math.degrees(az_rad), math.degrees(el_rad)


def load_targets(config: dict) -> dict[str, Target]:
    """Build key→Target map with az/el filled from config['site'] + config['targets']."""
    site = config["site"]
    lat = float(site["latitude"])
    lon = float(site["longitude"])

    out: dict[str, Target] = {}
    for key, spec in (config.get("targets") or {}).items():
        sat_lon = float(spec["sat_longitude"])
        az, el = geostationary_azel(lat, lon, sat_lon)
        out[key] = Target(
            key=key,
            name=spec.get("name", key),
            sat_longitude=sat_lon,
            band=spec.get("band", ""),
            az=az,
            el=el,
        )
    return out


@click.group()
def cli() -> None:
    """Tracker target presets."""


@cli.command("list")
@click.option(
    "--config",
    "config_path",
    type=click.Path(dir_okay=False, path_type=Path),
    default=DEFAULT_CONFIG_PATH,
    show_default=True,
    help="Path to config YAML.",
)
def list_cmd(config_path: Path) -> None:
    """List configured GEO targets with computed look-angles."""
    if not config_path.exists():
        raise click.ClickException(f"Config file not found: {config_path}")
    with config_path.open("r", encoding="utf-8") as f:
        config = yaml.safe_load(f) or {}

    targets = load_targets(config)
    site = config["site"]
    console = Console()
    console.print(
        f"Site: [bold]{site.get('name', '?')}[/bold]  "
        f"lat={site['latitude']:.4f}  lon={site['longitude']:.4f}  "
        f"elev={site.get('elevation', 0)} m"
    )

    table = Table(title="Geostationary targets")
    table.add_column("key", style="cyan")
    table.add_column("name")
    table.add_column("sat_lon", justify="right")
    table.add_column("az", justify="right")
    table.add_column("el", justify="right")
    table.add_column("visible", justify="center")

    for t in targets.values():
        visible = "✓" if (t.el is not None and t.el >= 0) else "✗"
        table.add_row(
            t.key,
            t.name,
            f"{t.sat_longitude:+.1f}°",
            f"{t.az:.2f}°" if t.az is not None else "-",
            f"{t.el:.2f}°" if t.el is not None else "-",
            visible,
        )
    console.print(table)


if __name__ == "__main__":
    cli()

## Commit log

2026-01-29 Initial project plan for radio telescope and antenna tracker
    Research and planning document covering:
    - Automated weather satellite reception (Meteor-M LRPT/HRPT, Metop, Elektro-L)
    - Custom AZ/EL antenna tracker design (ESP32, NEMA23 steppers)
    - Weather prediction AI for Warsaw (ConvLSTM/U-Net nowcasting)
    - Future radio astronomy expansion (hydrogen line, pulsars)
    - Incremental build path from ~$100 to full station
    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
2026-02-14 Add complete software foundation for multi-band radio telescope
    Implements the full Phase 0 software stack for a unified antenna tracker
    system capable of weather satellite reception, hydrogen 21cm mapping,
    and maser detection (inspired by Eduard Mol's EUCARA 2023 work).
    Tracker: stepper motor controller with trapezoidal acceleration, AS5600
    encoder feedback, EasyComm2/rotctld TCP server for Gpredict/SatDump,
    celestial coordinate transforms with LSR velocity correction, and
    multi-target observation scheduler.
    SDR: RTL-SDR IQ capture, Welch-method spectral averaging, ON/OFF
    bandpass calibration, LNB power/band control, and a complete maser
    detection pipeline following Mol's method (long int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
    [masers.csv]
2026-02-14 Add complete CAD files, Fusion 360 scripts, and hardware specs
    OpenSCAD parametric models for all 22 tracker parts (az base,
    turntable, worm gears, el yoke, dish clamps, feed bracket, electronics
    box). Fusion 360 API scripts for generating the same parts. Detailed
    1300-line dimension spec sheet with BOM, print settings, ASCII
    cross-sections, and assembly checklist. VirtualBox VM provisioning
    script for running Fusion 360 on Linux.
    [assembly.scad, az_base.scad, dish_clamp.scad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]
2026-02-14 Add design sketch and update gitignore
    Add hand-drawn tracker design sketch from GitHub issue #1 showing
    belt-driven alt-az mount concept. Add .FCBak to gitignore.
2026-02-18 Add project plan to repo
    Full plan for multi-band radio telescope: belt-driven 3D printed
    alt-az tracker, swappable feeds, 6 build phases, BOM under 200 EUR.
2026-02-23 Rewrite bootstrap for Debian Trixie + lgpio, fix EL microstepping
    - bootstrap_rpi.sh: install python3-lgpio as primary GPIO lib, pigpio/RPi.GPIO
    optional, remove pigpiod systemctl, add USB boot enable, create ~/start-web.sh
    - requirements.txt: lgpio primary, pigpio/RPi.GPIO commented out
    - config.yaml: elevation microstepping 16→32 (all DIP switches ON)
    - controller.py: lgpio backend with pigpio fallback
    - web/app.py: in-process lgpio debug page (hold/step/sweep endpoints)
    - spin_test.py + motor_test.py: direct lgpio motor test scripts
    - Remove outdated CAD (worm gear), old SDR/weather/scheduler stubs
    [assembly.scad, az_base.scad, dish_clamp.scad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]
2026-04-28 Rebuild from scratch with inmarsat seams (plan_2)
    Wipe legacy tracker/, web/, scripts/ and rebuild all modules cleanly
    with architectural seams for the upcoming inmarsat-sniffer integration:
    - bands/targets/sniffer config blocks in tracker/config.yaml
    - tracker/targets.py: geostationary look-angle math + presets
    - tracker/sniffer.py: subprocess supervisor stub (NotImplementedError
    with stable message pointing at docs/archive/merge_plan.html)
    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
2026-04-28 Fix motor stepping: drive HAT mode pins, widen STEP pulse
    Bench-confirmed against Waveshare's reference HR8825 driver — our motor
    controller had the HR8825 in indeterminate microstep mode because mode
    pins (16/17/20/21/22/27) were never driven. With DIPs all-1 the chip
    expects software to set MODE0/1/2 explicitly; floating pins led to
    beep-stall with no rotation.
    Also widen STEP HIGH pulse from 2-5 us to 200 us (HR8825 needs more
    margin than the datasheet minimum in practice), and drop motor_test's
    hardcoded min_sps clamp from 50 to 1 so slow debug speeds aren't
    silently sped up.
    - tracker/controller.py: claim mode pins low at axis init, _STEP_PULSE_S 200us
    - scripts/motor_test.py: claim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
    [controller.py]
2026-04-28 Use Waveshare HR8825 driver as motor backend
    Custom stepping logic in motor_test.py wasn't producing rotation —
    wrong enable polarity, mode-pin handling, or pulse timing depending
    on which patch we tried. Switched to Waveshare's reference HR8825
    driver verbatim (vendored as tracker/hr8825.py from their published
    sample code) and rewrote scripts/motor_test.py as a thin click CLI
    wrapper around it. Bench-verified: motor 2 rotates correctly under
    this wrapper at full step / 100 sps.
    Note: motor 1 stopped responding even with Waveshare's own demo —
    likely chip or motor damage from extended beep-stall during diagnosis.
    Hardware swap probably needed before motor 1 returns. tracker/controller.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
2026-04-28 controller: route stepping through HR8825; reset axis limits
    StepperAxis now instantiates Waveshare's HR8825 driver in __post_init__
    and routes step()/move_steps()/enable()/disable() through it. Sim mode
    still uses _SimGpio. config.yaml axis limits reset to full range
    (AZ 0-360, EL 0-90) — the limit-wizard had wedged them at near-zero
    during diagnosis, causing every goto_deg to clamp to 0 and silently
    return without stepping.
    Bench-confirmed: motor 2 (EL axis) rotates correctly via the FastAPI
    dashboard's jog/goto with this stack:
    web/app.py -> controller.AntennaTracker -> StepperAxis -> HR8825
    Motor 1 (AZ) is still hardware-dead from earlier overheat, will need a
    HAT or motor swap.
    C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
    [config.yaml, controller.py]
